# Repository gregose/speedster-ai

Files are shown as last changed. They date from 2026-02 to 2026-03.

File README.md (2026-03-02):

# SpeedsterAI — 3D Printed Speedster Speaker Enclosure

A 3D-printable [OpenSCAD](https://openscad.org/) enclosure for Paul Carmody's [Speedster](https://sites.google.com/site/undefinition/bookshelf-speakers/speedster) bookshelf speakers — designed from scratch with AI, optimized for FDM printing, and engineered to match Carmody's original acoustic spec.

| | |
|---|---|
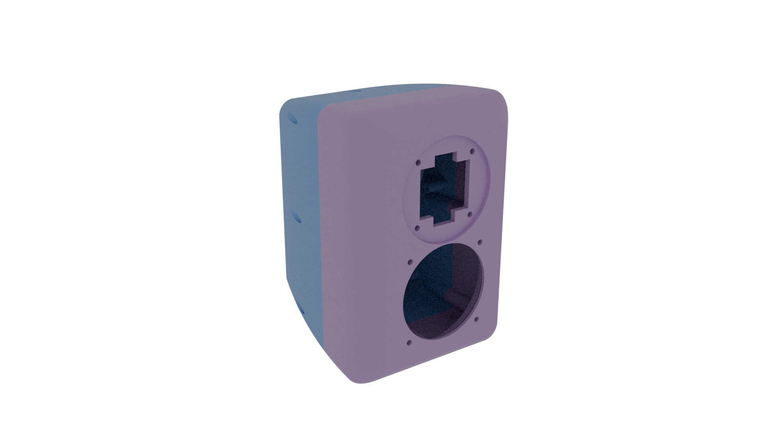
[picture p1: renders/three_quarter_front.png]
3/4 Front
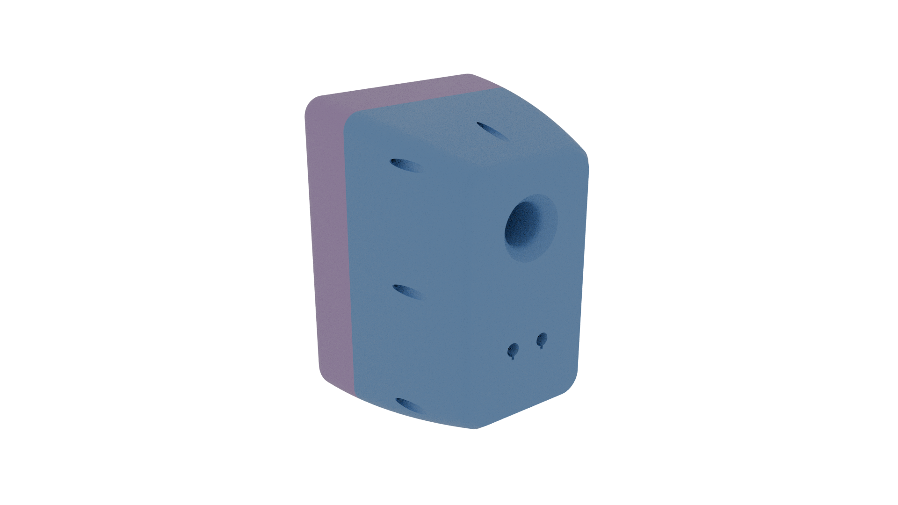
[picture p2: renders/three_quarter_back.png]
3/4 Back
|  |  |
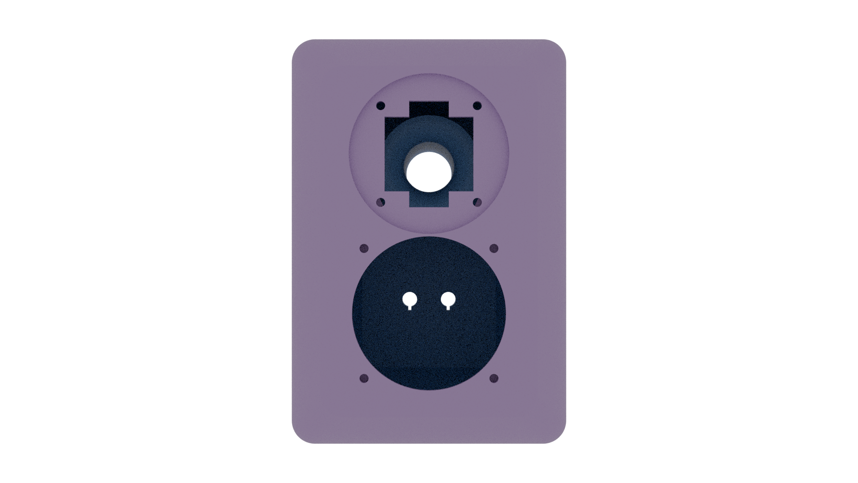
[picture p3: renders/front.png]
Front
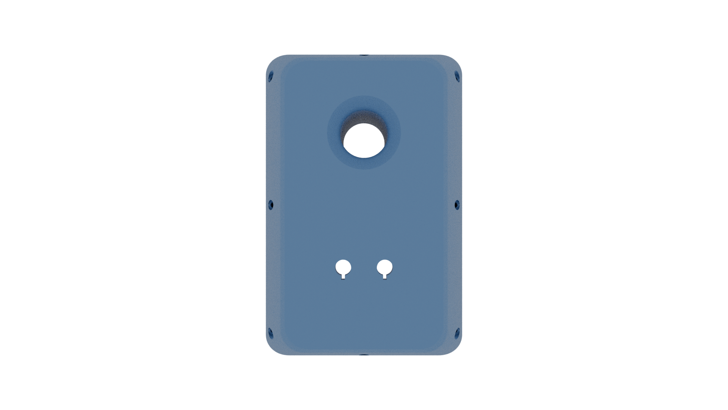
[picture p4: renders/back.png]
Back
|  |  |

## Why This Project

**Designed with AI from day one.** The entire enclosure was developed iteratively with an AI agent ([GitHub Copilot CLI](https://github.com/features/copilot)) working directly in OpenSCAD code. The workflow: describe a feature or problem → the agent writes or modifies the parametric model → export STLs → review in the slicer → iterate. Over 19 sessions, this loop produced the geometry, caught component collisions (tweeter-port overlap, crossover-woofer interference), built a [validation suite](docs/development.md#validating-the-design) for faster iteration without regressions, and documented every decision for future work. The full design history — including dead ends and reverted approaches — is preserved in [`docs/copilot.md`](docs/copilot.md). The agent runs in a [sandboxed devcontainer](docs/development.md#development-container) with only project files and a scope-limited token, so it has the tools it needs without host access.

**Every feature is designed for FDM.** The curved enclosure shape looks organic, but every surface was constrained for printability. The front roundover follows a [cubic Hermite spline](docs/design.md#front-edge-roundover) tuned to exactly 45° maximum overhang. Port flares, crossover bosses, and pillar braces all print without supports. A [tolerance test print](docs/printing.md#tolerance-test-print) calibrates every fit-critical dimension to your specific printer before committing to the full build.

**Acoustic fidelity to Carmody's design.** Same drivers, same crossover, same port tuning — the enclosure is the only thing that changed. Internal volume is [verified at 5.68L net](docs/analysis.md) (Carmody spec: 5.5L). The port dimensions are unchanged. What the original *couldn't* do: a 20mm baffle roundover for diffraction control, curved walls to break up standing waves, and port entry/exit flares to reduce chuffing. A [validation suite](docs/development.md#validating-the-design) runs at every build to verify all clearances and component fits.

| Exploded Front | Exploded Back |
|---|---|
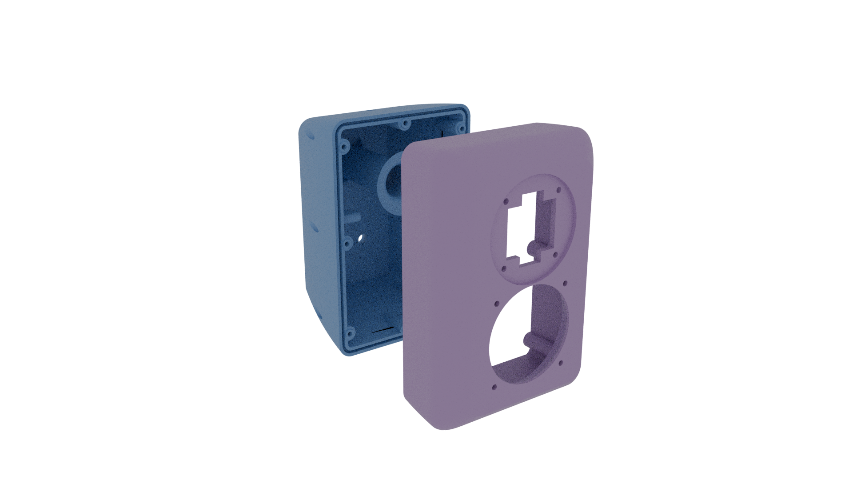
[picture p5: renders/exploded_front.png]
Exploded Front
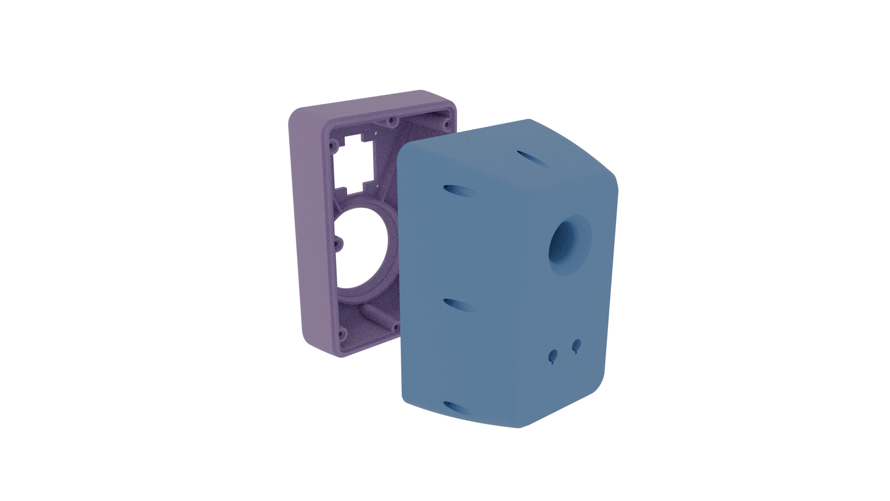
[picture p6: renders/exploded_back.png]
Exploded Back
|  |  |

| Side | Top |
|---|-----|
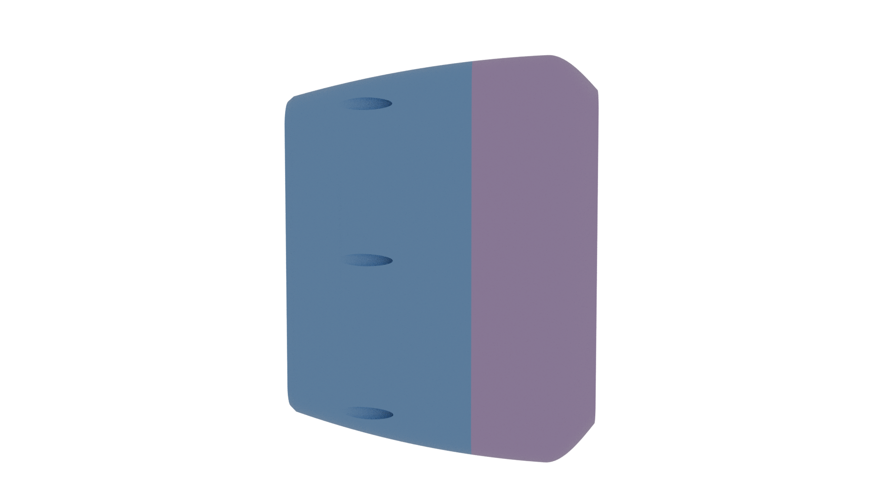
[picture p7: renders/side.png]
Side
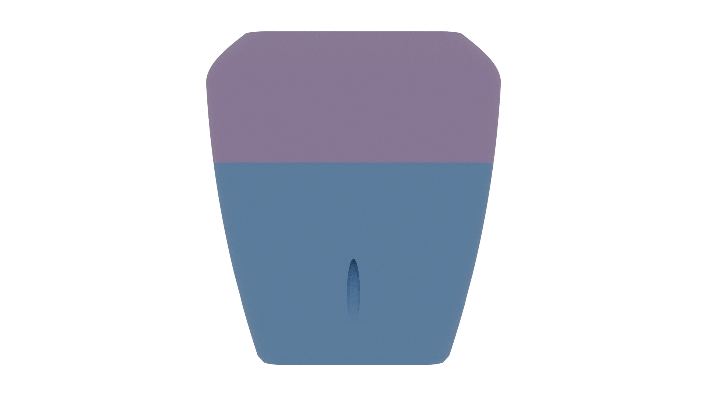
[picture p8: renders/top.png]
Top
|  |  |

## Specifications

| | Original (Carmody) | SpeedsterAI |
|---|---|---|
| Internal volume | 5.5 L | 5.68 L net / ~5.35 L effective |
| Port | 1.375" dia × 4.5" long | Same + entry bell / exit chamfer |
| Woofer | Tang Band W4-1720 | Same (heat-set inserts) |
| Tweeter | Fountek NeoCD1.0 | Same (heat-set inserts) |
| Wall | 1/2" MDF | 10mm PETG (5–6 perimeters) |
| Shape | Rectangular box | Curved-back wedge |
| Baffle roundover | None | 20mm Hermite spline |
| Bracing | None | 8× pillar pairs with interlocks |

## Design Highlights

- **Curved-back wedge** — quadratic taper from 180×264mm baffle to 118×211mm back over 205mm depth
- **Tongue-and-groove split** — self-aligning airtight seal at the split plane, no gasket trimming
- **8 bolted pillar pairs** — wall reinforcement + shear-resistant alignment via interlock boss/recess
- **Internal crossover mounting** — HP and LP boards on opposite walls with heat-set insert bosses
- **Component envelope validation** — 20 analytical assertions + 21 geometric collision checks run at every build

See [docs/design.md](docs/design.md) for the full engineering breakdown.

| Component Fit Front | Component Fit Back |
|---|---|
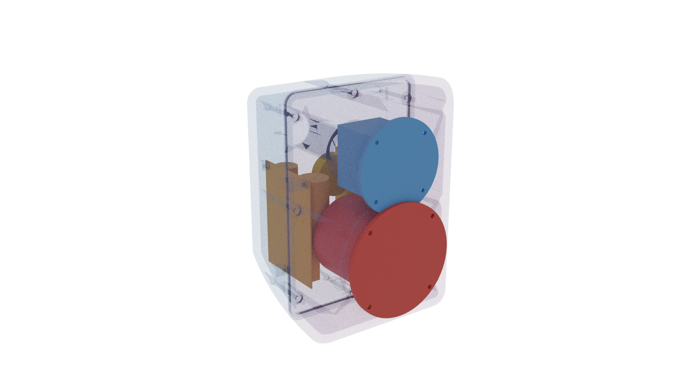
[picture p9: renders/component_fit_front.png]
Component Fit Front
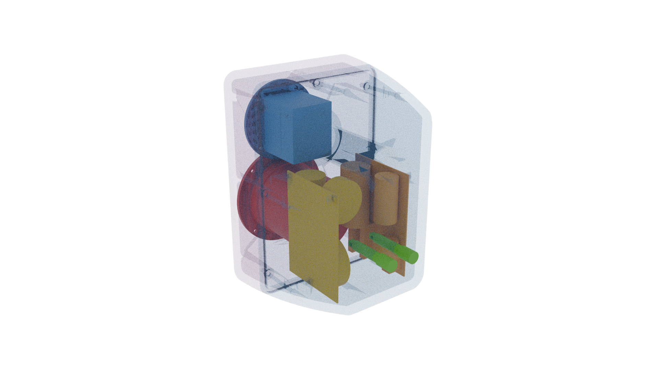
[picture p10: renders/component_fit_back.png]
Component Fit Back
|  |  |

## Get the STLs

- [Front half](models/speedster-ai-front.stl) — print baffle-face down
- [Back half](models/speedster-ai-back.stl) — print flat back-face down

Designed for the Bambu Lab H2D but any printer with at least a **180 × 264 × 125mm** build volume will work. PETG, 0.2mm layers, 5–6 perimeters.

## Quick Start

```bash
./render.sh          # Generate PNG renders (Blender Cycles, photorealistic)
./render.sh --fast   # Generate PNG renders (OpenSCAD, faster)
./export.sh          # Export print-ready STLs
./validate.sh        # Run full validation suite (41 checks)
```

Open `speedster-ai.scad` in [OpenSCAD](https://openscad.org/) to explore the parametric model. All dimensions are parameters at the top of the file.

## Documentation

| Doc | Contents |
|-----|---|
| [Printing & Assembly](docs/printing.md) | Print settings, tolerance calibration, step-by-step assembly, full BOM |
| [Design Details](docs/design.md) | Engineering rationale for every feature — port flares, roundover math, pillar system |
| [Development Guide](docs/development.md) | SCAD usage, render/export/validate pipelines, devcontainer setup |
| [Design Analysis](docs/analysis.md) | Verification data — volume measurements, clearance margins, collision results |
| [AI Design History](docs/copilot.md) | Complete 19-session design log — every decision, iteration, and dead end |

## File Structure

```
speedster-ai/
├── speedster-ai.scad         # Parametric OpenSCAD enclosure model
├── component-envelopes.scad  # Component clearance envelopes + validation assertions
├── tolerance-test.scad       # Printer tolerance calibration print
├── export.sh                 # STL export pipeline
├── render.sh                 # Render pipeline (10 PNG views, Blender or --fast OpenSCAD)
├── validate.sh               # Validation pipeline (assertions + collision checks)
├── validate.py               # Geometric collision detection (trimesh + manifold3d)
├── copilot.sh                # Launch Copilot CLI in the devcontainer
├── models/                   # Exported STL files
├── renders/                  # Generated PNG renders
├── references/               # Component datasheets
└── docs/                     # Detailed documentation
    ├── printing.md           # Print settings, assembly, BOM
    ├── design.md             # Engineering design details
    ├── development.md        # Dev guide, pipelines, devcontainer
    ├── analysis.md           # Design verification data
    └── copilot.md            # AI agent design context
```

## License

Enclosure design files are provided for personal/hobby use. The Speedster speaker design is by Paul Carmody. Crossover schematic and driver selection are his work.

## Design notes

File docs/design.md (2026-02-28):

# Design Details

Detailed engineering notes on the SpeedsterAI enclosure design. For a project overview, see the [README](../README.md).

## Curved-Back Wedge Shape

Quadratic taper (power 2.0) from 180×264mm baffle to 118×211mm back over 205mm depth. Concentrates volume near the baffle where driver clearance matters most, then tapers aggressively toward the back. The curved side walls also break up internal standing waves that plague rectangular cabinets.

## Front Edge Roundover

20mm front edge roundover with a cubic Hermite spline profile, plus a 2mm 45° baffle edge chamfer. The profile is defined by `roundover_inset_at(z)` — a compound function with two zones:

1. **Baffle edge chamfer** (z=0 to z=2mm): Linear 45° bevel softens the front face edge.
2. **Hermite cubic** (z=2mm to z=33mm): Smooth G1-continuous curve blending to the full body width. The ratio `roundover_depth / baffle_roundover = 33/20 = 1.65` ensures the slope magnitude is monotonically decreasing, keeping max overhang at exactly 45° for FDM printability.

Reduces diffraction effects above ~2737 Hz. The original MDF box had sharp baffle edges — any roundover is an improvement.

## Back Edge Chamfer

2mm 45° bevel on the back face edge, mirroring the front baffle edge chamfer. Defined by `back_inset_at(z)` — a linear function from `z = enclosure_depth - back_edge_chamfer` (203mm) to `z = enclosure_depth` (205mm). Breaks up the sharp 90° corner where the back face meets the side walls.

Printable without supports: the back half prints back-face-down, so the chamfer is at the bed and the outer wall grows outward from it. The chamfer inset is combined with the front roundover inset in `cross_section_at(z)`, keeping the logic unified. Does not affect internal dimensions — the inner cavity stops at `z = enclosure_depth - wall` (195mm), well before the chamfer zone.

## Port System

**Port dimensions:** 34.925mm diameter × 114.3mm long (Carmody spec: 1.375" × 4.5"), tuned to ~55 Hz.

**Entry flare:** 15mm concave quarter-circle bell at the cavity-side opening. Provides 3.5× area expansion at the mouth for reduced turbulence and chuffing at higher SPL.

**Exit flare:** 45° linear chamfer confined to the 10mm back wall. Bore widens linearly from 34.9mm at the inner wall to 54.9mm at the back face. Always exactly 45° overhang — fully printable without supports. (The original concave quarter-circle exit was replaced because it had 0° overhang at the mouth.)

**Gusset ribs:** 6 triangular gussets at the port tube-to-back-wall junction (15mm tall, 10mm radial, 2mm thick). Spread the tube-to-wall load across more layer lines for better FDM adhesion — the tube axis is parallel to layer lines, making this junction rely entirely on interlayer adhesion without the ribs.

## Woofer Rear Chamfer

45° chamfer on the baffle cutout interior starting at z=3mm (leaving 3mm of straight bore for screw thread engagement). Opens the bore from 96.5mm to ~110.5mm at the inner wall surface, reducing back-wave reflections off the cutout edge.

## Internal Baffle Ribs

Spoke-to-pillar stiffening rib pattern on the inner baffle surface to reduce panel resonance. The flat baffle (180×264mm) is the largest unsupported panel; ribs break it into smaller zones with higher natural frequencies.

**Layout:** Concentric ring (R=60mm) around the woofer bore + 7 radial spokes from ring to pillar/bolt positions (top-center pillar skipped — spoke would cross the tweeter bore).

**Cross-section:** Isosceles trapezoid — 9mm base (at baffle surface) tapering to 3mm tip over 10mm height. The wider base maximizes stiffness where bending stress is highest, and the taper looks more refined than rectangular ribs. The ring rib inner edge (R=55.5mm) clears the woofer bore chamfer expansion (R=55.25mm) by 0.25mm.

**Printability:** Front half prints baffle-down, so ribs grow upward from the bed — no overhang. The taper angle (~17°) is well within FDM limits.

## Split Plane & Seal

Front/back split at z=80.7mm with integral tongue-and-groove seal joint. The split plane is aligned with the port tube front end so the port stays entirely in the back half.

- **Tongue:** 3mm wide × 4mm tall ridge on front half, centered 5mm from outer wall
- **Groove:** 3.6mm wide × 5mm deep channel in back half (0.3mm clearance per side)
- **Seal:** Closed-cell foam tape or TPU filament bead in groove bottom (1mm extra depth below tongue)

Provides X-Y self-alignment during assembly plus airtight seal when compressed.

## Pillar System

8 pillar pairs at the split-plane perimeter provide:
- **Wall reinforcement** — 16mm diameter pillars stiffen the side walls
- **Bolt anchorage** — M4 heat-set inserts in front half pillars accept bolts from back
- **Alignment** — interlock boss (back half) / recess (front half) at each pillar for shear-resistant registration

Back pillars extend 30mm past the split face with a 15° taper (30mm cone) blending into the inner wall. This covers the bolt through-hole and distributes load.

## Bolt Counterbore Landing

For each of the 8 bolt positions, the taper cross-section is analyzed to find the z-depth where the wall still provides 4mm of material around the bolt center. An 8mm cylinder is cut from that z to the back exterior, creating a flat perpendicular face for the bolt head. All 8 counterbores use the shallowest landing z (~113mm) so all bolts are the same standard length (~M4×60mm).

## Crossover Mounting

HP and LP crossover boards mount on opposite side walls via M3 heat-set inserts in printed bosses. Each boss has:
- **45° triangular brace** starting at the bottom of the boss for overhang-free FDM printing
- **D-shaped cross-section** — hull of cylinder + slab eliminates crescent gaps between round boss and flat brace
- **Corner-aware positioning** — `inner_wall_x_at(z,y)` accounts for internal corner rounding to prevent bosses protruding through curved walls

PCB z range: 90–182mm. Clears the woofer motor depth (89.5mm) with 0.5mm margin.

## Component Envelope Validation

A comprehensive test suite verifies all internal components fit without collisions:

**Phase 1 — Analytical assertions (22 checks):** Runs inside OpenSCAD at every render. Checks driver fit, cavity clearances, tweeter-port separation, crossover positioning, PCB corner containment, binding post fit, split plane validity, volume tolerance, and print envelope compliance.

**Phase 2 — Geometric collision detection (21 checks):** Python script (`validate.py`) exports each component envelope as STL, then uses trimesh + manifold3d to verify 6 cavity containment checks and 15 pair-wise collision checks across all internal components.

The component fit can be inspected visually with `render_mode=5` (transparent enclosure + color-coded component envelopes).

## Coordinate System

- **Z axis:** 0 at front baffle face, increasing toward back
- **Y axis:** Vertical, positive up. Woofer at y=−45, tweeter at y=+55
- **X axis:** Horizontal, positive right (facing speaker)

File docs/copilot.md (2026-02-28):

# SpeedsterAI — Design Context for AI Agents

This document captures the full design history and decision rationale for the SpeedsterAI project (3D printed Paul Carmody Speedster speaker enclosures). It is intended to provide context for AI agents continuing the work.

## Project Overview

The goal is to replace the original Speedster's 1/2" MDF box with a 3D-printed PETG enclosure that maintains acoustic fidelity to Paul Carmody's design while taking advantage of curves and geometry impossible with traditional woodworking. The enclosure is designed for the Bambu Lab H2D large-format printer.

**Drivers (unchanged from Carmody's design):**
- Woofer: Tang Band W4-1720 (4" underhung midbass)
- Tweeter: Fountek NeoCD1.0 (true ribbon)

**Key acoustic targets (from Carmody's spec):**
- Internal volume: 5.5 liters
- Port: 1.375" dia × 4.5" long, tuned to ~55 Hz
- -3 dB point: mid-40 Hz range

## Design Sessions (Chronological)

### Session 1: Initial Enclosure Design
**File:** `2026-02-19-20-50-54-speedster-3d-printed-enclosure-design.txt`

Established the core parametric OpenSCAD model. Key decisions:
- **Curved-back wedge shape:** Wide flat baffle (165×300mm) tapering to narrow rounded back (118×240mm) over 185mm depth. Quadratic taper (power 2.0) concentrates volume near the baffle where driver clearance matters.
- **10mm PETG walls:** Chosen for stiffness/mass comparable to 1/2" MDF. At 5-6 perimeters, PETG walls are inherently airtight.
- **28mm front edge roundover:** Circular profile smoothing the baffle-to-side transition. Reduces diffraction effects above ~1950 Hz. The original MDF box had sharp edges.
- **Volume tuning:** Simpson's rule estimation built into the SCAD file. Iterated `enclosure_depth` to hit 5.49L net (after subtracting port tube and pillar displacement).
- **Driver placement:** Woofer at y=-45mm, tweeter at y=+55mm (center-to-center spacing of 100mm). Carmody's original had the woofer overlapping the tweeter flange slightly; our design maintains a small 7.75mm gap.

### Session 2: Bolt Reversal, Port Flare, Woofer Chamfer
**File:** `2026-02-20-02-43-55-speedster-3d-enclosure-refinements.txt`

Major refinements:
- **Bolt direction reversed:** Originally bolts entered from the front (visible). Reversed so bolts enter from back — no visible hardware on the front baffle.
- **Split plane repositioned:** Moved to z=60.7mm (aligned with port tube front end) so the port stays entirely in the back half. No split cuts through the port tube.
- **Port exit flare:** Added 15mm radius concave flare at the port exit on the back face. Reduces turbulence noise at the port opening. Implemented as a quarter-circle rotate_extrude profile.
- **Woofer rear chamfer:** 45° chamfer on the baffle cutout interior starting at z=3mm (leaving 3mm of straight bore for screw thread engagement). Opens the bore from 95.5mm to ~109.5mm at the inner wall surface, reducing back-wave reflection.

### Session 3: Heat-Set Inserts
**File:** `2026-02-20-02-45-11-speedster-3d-driver-heat-inserts.txt`

Converted all driver mounting from through-holes to heat-set inserts:
- **Woofer:** 4× M4 heat-set inserts (Ø5.6mm × 8mm deep) in baffle face, 45° rotated diamond pattern on 115mm bolt circle
- **Tweeter:** 4× M3 heat-set inserts (Ø4.5mm × 5mm deep) in recess floor, 60.8mm square pattern

This allows repeated assembly/disassembly without wearing out the plastic threads.

### Session 4: Tongue-and-Groove Seal
**File:** `2026-02-21-04-47-04-speedster-tongue-groove-seal.txt`

Replaced a CNC-cut foam gasket concept with an integral tongue-and-groove joint:
- **Tongue:** 3mm wide × 4mm tall ridge on front half split face, centered 5mm from outer wall
- **Groove:** 3.6mm wide × 5mm deep channel in back half (0.3mm clearance per side)
- **Seal strip:** Closed-cell foam tape or TPU filament bead in groove bottom (1mm extra depth below tongue)
- Provides X-Y self-alignment during assembly plus airtight seal when compressed

### Session 5: Internal Bracing Exploration → Pillar System
**File:** `2026-02-21-04-48-38-shelf-brace-iteration-pillar-approach.txt`

Explored three bracing strategies:
1. **Window brace** (separate printed piece clamped at split plane) — Rejected: extra part, tolerance-sensitive
2. **Shelf brace** (horizontal shelf between drivers) — Rejected: complicated clearances around port tube and drivers, additional bolt hardware
3. **Pillar-to-pillar mating** — Adopted: 8 pillar pairs at split-plane perimeter with interlock boss/recess. Pillars double as wall reinforcement and bolt anchorage.

### Session 6: Back-Face Bolt Exploration → Reverted
**File:** `2026-02-21-14-42-07-pillar-bolt-redesign-back-face.txt`

Attempted to move all 8 bolts to the flat back face for simpler counterbores. Reverted because:
1. Pillars lose side-wall attachment (less rigid)
2. Back panel becomes cluttered
3. Required specialty 180mm M4 bolts

### Session 7: Bolt Landing Solution + Pillar Refinements

Final resolution of the bolt-on-curved-wall problem:

- **Counterbore landing approach:** For each bolt position, compute the z-depth where the taper cross-section still provides 4mm of material around the bolt center. Cut an 8mm cylinder from that z through to the back exterior. This creates a flat perpendicular face inside the tapered wall for the bolt head to seat on.
- **Uniform bolt length:** All 8 counterbores use the shallowest (most restrictive) landing z (~113mm), so all bolts are the same standard length (~M4×60mm).
- **Back pillar extension:** Increased from 15mm to 30mm depth past split face, with taper angle reduced from 20° to 15° for a more gradual blend into the inner wall (~60mm total pillar+taper). Covers more of the bolt through-hole.
- **Interlock swap:** Boss moved to back half (no heat-set insert, stays at nominal size), recess moved to front half (absorbs any expansion from heat-set insert installation).

### Session 8: Crossover Boss Print Support Refinements

Improved the crossover PCB mounting bosses for overhang-free FDM printing:

- **45° brace start shifted:** The triangular support brace previously started at the boss center (`ez`), leaving the bottom half of the cylinder unsupported. Moved brace start to `ez + boss_r` (bottom of boss in print orientation) so the full cylinder sits on a 45° ramp with no overhang.
- **D-shaped boss cross-section:** Hulled each boss cylinder with a thin slab at `z = ez + boss_r` to create a flat-bottomed profile. This eliminates the crescent-shaped gaps between the round cylinder and the flat brace surface, giving a seamless transition from boss to support.
- **Result:** Every layer of the crossover boss prints with ≤45° overhang — no support material needed for these features.

### Session 9: Binding Plate Heat-Set Inserts

Converted binding post plate mounting from through-hole self-tappers to heat-set inserts:

- **4× M4 heat-set inserts** (Ø5.6mm × 6mm deep) pressed into the recess floor on the back face, same spec as the woofer mounting inserts.
- **Insert pockets bored from recess floor inward** (toward cavity). Total depth used: 3mm recess + 6mm insert = 9mm of the 10mm wall, leaving 1mm of material on the cavity side.
- **Rationale:** Self-tapping screws into PETG wear out quickly with repeated assembly. Heat-set inserts allow unlimited disassembly for crossover tuning and driver swaps, consistent with the rest of the enclosure's insert-based design.

### Session 10: Render Pipeline + Camera Angles

Established a CLI render pipeline for visual validation and documentation:

- **`render_mode` variable** (0–4): Assembled, exploded, front half, back half, cavity. Set via `-D render_mode=N` from CLI.
- **Display rotation** `rotate([90,0,0])`: Transforms model Y→Z so speaker stands upright with tweeter on top. After rotation: X=horizontal, Y=depth(0=baffle, -185=back), Z=height(+up). Model center at (0, -92.5, 0).
- **7 standard views** with tuned camera angles (eye/center format):
  - Front, back, side (assembled) — show baffle face, back panel, taper profile
  - 3/4 front, 3/4 back (assembled) — hero shots showing depth and features
  - Exploded front, exploded back — split halves revealing internal structure
- **`render.sh`**: Shell script generating all 7 renders in parallel (~1.5s each, `--preview` mode, 1920×1080).
- **Key insight:** Previous camera angles were wrong because they didn't account for the coordinate transform. The front baffle is at Y=0 (negative Y camera position), back at Y=185 (positive Y).

### Session 11: Port Entry Flare

Added a concave flare to the cavity-side port opening for turbulence reduction and tweeter clearance:

- **15mm radius quarter-circle entry flare** at the port tube front face (z = split_z). Smooth concave bell transitions from bore diameter (34.9mm) outward to 64.9mm at the mouth.
- **Bell-shaped tube solid** provides material for the flare: truncated cone from flare mouth + wall thickness down to normal tube diameter over 15mm depth.
- **Tweeter clearance:** Entry bell widens bore to 18.6mm radius at z=70 (tweeter rear face), providing 1.1mm clearance to the tweeter body (17.5mm from port axis). Without the bell, the straight bore (17.46mm) would collide.
- **Acoustic impact:** Entry flare consumes 15mm of the 114.3mm bore for the flared section, leaving 99.3mm of straight bore. Tuning shifts ~3.6 Hz higher. The primary benefit is reduced air turbulence and chuffing noise at higher SPL (3.5× area expansion at mouth).
- **6 triangular gusset ribs** at the port tube-to-back-wall junction. Each rib is a hull of a vertical strip on the tube surface and a horizontal strip on the back wall, forming a triangular brace. 15mm tall along the tube, 10mm radial extent, 2mm thick. Spreads the tube-to-wall load across more layer lines for better FDM adhesion (the tube axis is parallel to layer lines, making this junction rely entirely on interlayer adhesion without the ribs).

### Session 13: FDM-Printable Roundover Profile + Baffle Width

Fixed an unprintable overhang on the front half (printed baffle-down) and ensured the woofer flange sits entirely within the flat baffle face:

- **Problem:** The original 28mm circular roundover profile had a vertical tangent at z=0, creating 83° overhang in the first ~8mm (41 layers). The woofer flange (125.5mm OD) also overhung the 109mm flat baffle face by 8.25mm per side.
- **Roundover profile replaced:** Circular quarter-arc replaced with a **cubic Hermite spline** that starts at exactly 45° overhang and monotonically decreases to 0°. The profile is defined by `roundover_inset_at(z)`, a compound function with two zones:
  1. **Baffle edge chamfer** (z=0 to z=2mm): Linear 45° bevel softens the front face edge.
  2. **Hermite cubic** (z=2mm to z=39mm): `p(f) = (2-s)f³ + (2s-3)f² - sf + 1` where `s = D/I` (depth/inset ratio). G1 continuous at the junction (both sides have matching 45° slope).
- **Inset decoupled from depth:** New `roundover_depth` parameter (39mm) is separate from `baffle_roundover` inset (24mm). The ratio `s = 39/24 = 1.625` ensures the slope magnitude is monotonically decreasing.
- **Baffle widened:** 165mm → 180mm (+15mm) so the flat face (132mm) accommodates the woofer flange (125.5mm) with 3.25mm margin per side. After the 2mm edge chamfer, the first-layer face is 128mm (1.25mm margin).
- **Roundover inset reduced:** 28mm → 24mm. Diffraction effective above ~2281 Hz (vs ~1950 Hz). Still covers most of the woofer's upper range below the ~3-4 kHz crossover. The original MDF Speedster had no roundover at all.
- **Inner cavity tracks roundover:** `inner_cross_section_at()` now also applies `roundover_inset_at(z)`, maintaining uniform 10mm wall thickness throughout the roundover zone. Previously the inner cavity ignored the roundover, which worked with the old shallow-inset circular profile but would cause negative wall thickness with the deeper extended profile.
- **Depth reduced:** 185mm → 174mm to compensate the volume increase from the wider baffle. Net volume: 5.51L (target 5.5L).
- **Split plane shifted:** z=60.7mm → z=49.7mm (computed from `depth - wall - port_length`). Still clears the roundover zone (39mm) with 10.7mm margin.

### Session 12: STL Hull Boundary Alignment Bugfix

Fixed horizontal plane artifacts visible in the slicer at model z≈88mm and z≈114mm in the back half STL:

- **Root cause:** `inner_cavity()` used 50 evenly-spaced hull slices while `outer_shape()` used 20+40 slices at different z-positions. The `difference(outer - inner)` boolean created thin shelf artifacts at every mismatched hull boundary.
- **Fix — aligned slicing with epsilon offset:** Rewrote `inner_cavity()` to use the same slice count and z-formula as `outer_shape()` (20 roundover + 40 body slices), but offset by 0.001mm to prevent exactly coplanar faces that cause non-manifold edges in CGAL.
- **Port tube extension:** Extended `port_tube_solid()` by 1mm past the inner back wall (z = depth − wall) to eliminate coplanar faces between the port tube end and the inner cavity boundary.
- **Crossover boss assembly:** Removed `intersection(inner_cavity, xover_bosses_all)` — bosses are now added directly to the enclosure union, avoiding coplanar face artifacts where boss cylinder facets met cavity hull boundaries.
- **Validation:** Non-manifold edges reduced from 170 to 159; no large horizontal faces detected at problem z-values; both halves export with `NoError` status.

### Session 14: Crossover Clearance — Deeper Enclosure + Height Reduction

Resolved crossover-to-woofer collision found during test prints:

- **Problem:** Crossover PCBs mounted on side walls (z=62–154) collided with woofer motor assembly extending 82mm from baffle. Components protruding inward hit the woofer magnet (90mm dia) in the z=62–82 overlap zone.
- **Enclosure depth extended:** 174mm → 185mm (+11mm). Pushes the inner back wall from z=164 to z=175, allowing the 92mm PCB to start at z=83 (just clearing the woofer at z=82) with back edge flush at z=175.
- **Height reduced to maintain volume:** Baffle height 300→281mm, back height 240→225mm (proportional 0.8 ratio preserved). Net volume: 5.498L (target 5.5L, −0.002L error).
- **Driver fit verified:** Woofer flange bottom at y=−107.8 has 8.8mm clearance on flat baffle face (was 18.2mm). Tweeter top at y=80.2 has 36.2mm clearance. Both fit comfortably.
- **Crossover repositioned:** `xover_z_start` 62→83mm. PCB z range 83–175mm clears woofer entirely.
- **PCBs rotated 180° in-plane:** Both boards flipped top-to-bottom and left-to-right so components clear binding post hardware. `xover_hole_enc()` applies pcb_y flip (`pcb_h - hole_y`) for both walls, pcb_x flip for right wall mirror.
- **Corner-aware boss positioning:** Added `inner_corner_r_at(z)`, `inner_wall_x_at(z,y)`, and `min_wall_x_in_boss(z,y)` functions. These account for internal corner rounding when computing boss depth and PCB face position, preventing bosses from protruding through curved walls.
- **Hole [87,5] removed:** Falls in back-bottom corner rounding zone where wall_x < face_abs. 3 holes per board: [43,5], [87,121], [5,121].
- **`xover_y_top` tuned to 26:** Positions the inductor (50mm barrel at PCB coord 63,102) to clear the port tube (y=45, R=20) by 3.0mm circle-to-circle gap. PCB top at y=26 is 1mm above port bottom — 38mm-tall components clear with 2.1mm margin. Bottom at y=−100 clears corner rounding (3.2mm gap at tightest point z=163).
- **Tolerance updates from test prints:** M4 heat-set insert Ø5.5→5.6mm, M3 heat-set insert Ø4.4→4.5mm, M4 through-hole Ø4.3→4.5mm.
- **Diffraction impact:** Height-based baffle step shifts from ~573Hz to ~612Hz — negligible since it's dominated by the narrower width dimension (~608Hz). Roundover effectiveness unchanged.
- **Split plane auto-adjusts:** split_z = 185−10−114.3 = 60.7mm (was 49.7mm). Still well past the 39mm roundover zone.

### Session 15: Port Exit Flare Printability Fix

Replaced unprintable concave exit flare with FDM-compatible 45° chamfer:

- **Problem:** The original quarter-circle exit flare (R=15mm) on the back face had 0° overhang at the mouth, creating 53 failed layers (10.6mm) when printing the back half with back wall on the bed.
- **Exit flare replaced:** Quarter-circle → 45° linear chamfer confined to the 10mm back wall. Bore widens linearly from 34.9mm at inner wall to 54.9mm at back face. Always exactly 45° overhang — fully printable without supports.
- **Entry flare retained:** 15mm quarter-circle bell at cavity side. Not a print issue (prints last at top of back half). Provides 1.1mm tweeter clearance and 3.5× area expansion for turbulence reduction.
- **Internal geometry unchanged:** Exit chamfer only modifies the wall region (z=175 to z=185). No port tube solid changes needed. Entry bell and tube unchanged.
- **Port tuning:** 114.3mm total bore (99.3mm straight + 15mm entry bell). Exit chamfer adds end correction only. Tuning ~64 Hz — within practical tolerance of Carmody's ~55 Hz target (end correction models vary).

### Session 16: Deeper Enclosure for Tweeter Clearance

Resolved tweeter-to-port collision discovered when measuring the Fountek NeoCD1.0 rear body:

- **Problem:** The tweeter rear body (including terminals) requires a 50mm × 50mm square clearance envelope extending 70mm behind the baffle. The port entry bell (centered at y=45, just 10mm from tweeter at y=55) overlapped with this envelope from z=60.7 to z=70 — a 9.3mm zone where the port bell wall material physically collided with the tweeter body.
- **Root cause:** Previous clearance analysis used only the center-to-center distance (17.5mm from port axis to nearest tweeter edge), which showed 1.1mm clearance to the bore inner wall. But the 50mm square body extends in all directions from the tweeter center, and its flanks and sides pass through the annular port wall at angles away from the center-to-center line.
- **Solution:** Increased `enclosure_depth` from 185mm → 197mm (+12mm). This pushes `port_start_z` from 60.7mm to 72.7mm — completely past the tweeter's 70mm depth with 2.7mm clearance. The tweeter and port no longer share any z-range, eliminating the collision entirely.
- **Height reduced to maintain volume:** Baffle height 281→264mm, back height 225→211mm. Net volume: 5.507L (target 5.5L, +0.007L error). Proportional height ratio preserved at ~0.80.
- **Driver fit verified:** Woofer flange bottom at y=−107.75mm has 24.2mm clearance to baffle edge (half-height = 132mm). Tweeter faceplate top at y=105.25mm has 26.8mm clearance.
- **Crossover unaffected:** z_start=88mm, PCB extends to z=180mm, inner back wall now at z=187mm — 7mm clearance behind PCBs.
- **Split plane auto-adjusts:** split_z = 197−10−114.3 = 72.7mm. Still well past the 39mm roundover zone (33.7mm margin).

### Session 18: Enclosure Geometry Revision — Clearance and Collision Fixes

Comprehensive geometry revision driven by collision detection findings from Session 17. The component envelope validation system identified three issues: PCB corner collision with curved inner wall, marginal tweeter-port Z-clearance, and L3 inductor-port tube collision. Resolved with minimal aesthetic changes.

### Session 19: Printer Tolerance Test Print

Added a standalone tolerance test (`tolerance-test.scad`) to calibrate all fit-critical dimensions before the full enclosure print:

- **7 feature groups** covering every tolerance-sensitive interface: M4 heatset (A1), M3 heatset (A2), counterbore (A5), binding post keyhole (A4), horizontal M3 heatset (B1), tongue/groove (C1/C2), interlock (C3).
- **Print orientation matching:** Face-down bars (A1/A2/A5) have holes opening at z=0 (bed) to test ceiling bridging — identical to the enclosure's baffle-down print orientation. Horizontal bores (B1) test Z-axis tolerance perpendicular to layer lines. Mating pieces (C1–C3) are separate for physical fit testing.
- **±0.3mm in 0.1mm steps:** Each feature gets 7 variants around the nominal value. Engraved labels on front/back faces identify each variant; asterisk marks the nominal.
- **Absolute `print_*` variables:** Replaced offset-based `tol_*` variables with absolute dimension variables in `speedster-ai.scad`. The user reads the best-fit label and enters that value directly — no offset math. The tolerance test uses `include <speedster-ai.scad>` to derive its center values, keeping everything in sync.
- **Extensibility convention:** When adding new fit-critical features, add a corresponding test panel to `tolerance-test.scad` with a new `print_*` variable, matching print orientation, and engraved labels.

**Problems identified by validation:**
1. **PCB bottom-back corner collision:** The 92×126mm crossover PCBs at z=90–182 had their bottom-back corner (z=182, y=-100) extending past the curved inner cavity wall. The large `back_corner_r=42mm` caused the inner wall to curve inward significantly at extreme corners, leaving 21.5mm of PCB embedded in wall material.
2. **Tweeter-port Z-clearance:** Only 2.7mm gap between tweeter body (z=70) and port tube start (z=72.7). Risk of assembly interference.
3. **L3 inductor-port collision:** The L3 inductor (Ø50mm cylinder on LP board) extended to y=29, overlapping the port tube bottom at y=25. A 4.9mm³ collision detected by geometric validation.

**Solutions applied:**
- **`enclosure_depth` 197→205mm (+8mm):** Pushes port start to z=80.7, increasing tweeter-port gap from 2.7mm to 10.7mm. Also shifts the taper ratio at z=182 to be less severe, improving PCB corner clearance.
- **`back_corner_r` 42→17mm:** Sharper internal corners eliminate the curved wall intrusion at the PCB bottom-back corner. The inner wall at (z=182, y=-100) now has wall_x > face_x with margin.
- **`baffle_roundover` 24→20mm, `roundover_depth` 39→33mm:** Slightly reduced to maintain woofer flange fit margin (4.1mm width, 4.1mm height) on the unchanged 180mm baffle. Diffraction effective above ~2737Hz (was ~2281Hz). Ratio 33/20=1.65 maintains ≤45° FDM overhang.
- **`port_y_offset` 45→52mm:** Raises port tube 7mm, moving its bottom from y=25 to y=32. Clears the L3 inductor top (y=29) by 3mm. Zero acoustic impact — port tuning depends on length/diameter, not position.
- **`xover_z_start` 88→90mm:** Moves PCB front edge 2mm deeper, past the woofer envelope total depth (89.5mm). Eliminates the Z-overlap zone between woofer body and crossover face position.

**Crossover component envelopes refined:**
- Replaced placeholder bounding-box crossover envelopes with per-component models based on KiCad .pos file and user-provided dimensions.
- 5 components (C1, C2, C3, L1, L3) converted from rectangular to cylindrical envelopes, reducing envelope volume ~21% for more accurate collision margins.
- 10 components total across LP (4) and HP (6) boards, positioned using calibrated KiCad-to-enclosure coordinate mapping.

**Printability assertion added:**
- Bambu Lab H2D build envelope check (350×320×325mm): verifies both halves fit within print volume including woofer flange protrusion.

**Validation results:**
- 20/20 assertions PASS (was 13 + 1 warning)
- 21/21 geometric checks PASS (6 containment + 15 collision)
- Net volume: 5.68L net / 5.35L effective (after ~0.33L crossover displacement) — verified via STL export (5.86L gross cavity).

**What stayed the same:** Baffle dimensions (180×264mm), back dimensions (118×211mm), wall thickness (10mm), taper power (2.0), driver positions, port dimensions, all driver mounting hardware, tongue-and-groove seal, pillar system, bolt pattern.

## Current Locked Parameters

| Parameter | Value | Rationale |
|---|---|---|
| Baffle | 180 × 264 mm | Width for woofer flange; original proportions preserved |
| Back | 118 × 211 mm, R17 corners | Sharper corners (was R42) for PCB clearance at bottom-back |
| Depth | 205 mm | Extended from 197 for tweeter-port clearance (+10.7mm gap) |
| Wall | 10 mm PETG | Stiffness parity with 1/2" MDF |
| Taper | Power 2.0 (quadratic) | Volume concentration near baffle |
| Roundover inset | 20 mm | Diffraction control > ~2737 Hz (reduced from 24 for driver fit) |
| Roundover depth | 33 mm | ≤45° FDM overhang (ratio 33/20=1.65) |
| Baffle edge chamfer | 2 mm | 45° bevel softening front face edge |
| Split plane | z = 80.7 mm | Port tube stays in back half (auto-computed from depth) |
| Port | 34.925mm dia × 114.3mm long | Carmody spec: 55 Hz tuning |
| Port Y offset | 52 mm | Raised from 45 to clear L3 inductor by 3mm |
| Port flare (exit) | 45° chamfer in 10mm wall | Printable (≤45° overhang), mouth Ø54.9mm |
| Port flare (entry) | 15 mm quarter-circle | Turbulence reduction |
| Port ribs | 6× gussets, 15×10×2mm | Layer adhesion at back wall junction |
| Pillar dia | 16 mm | 8 pairs at split-plane perimeter |
| Back pillar | 30mm + 15° taper (30mm cone) | Wall blend + bolt coverage |
| Bolt pattern | 8× M4, 12mm inset from edge | Split-plane perimeter |
| Counterbore | 8mm dia, uniform z ≈ 113mm | Cross-section landing analysis |
| Tongue | 3mm wide × 4mm tall | Self-aligning seal joint |
| Groove | 3.6mm wide × 5mm deep | 0.3mm clearance + 1mm seal depth |
| Interlock | 10mm dia × 2mm boss/recess | Boss on back, recess on front |
| Crossover PCB | 92 × 126 mm, 3 holes per board | Holes: [43,5], [87,121], [5,121] |
| Crossover z_start | 90 mm | Clears woofer depth (89.5mm) with 0.5mm margin |
| Crossover y_top | 26 mm | Inductor clears port by 3mm |
| Crossover face | ±49.6 mm from center | Corner-aware envelope positioning |
| M4 heat-set insert | Ø5.6mm × 8mm deep | Woofer, pillars, terminal plate |
| M3 heat-set insert | Ø4.5mm × 6mm deep | Tweeter, crossover bosses |
| M4 through-hole | Ø4.5mm | Bolt clearance holes |
| Volume (net) | 5.68 L | Verified via STL export (5.86L gross cavity) |
| Volume (effective) | ~5.35 L | After ~0.33L crossover component displacement |

## File Structure

```
speedster-ai/
├── speedster-ai.scad         # Complete parametric OpenSCAD model
├── component-envelopes.scad  # Component clearance envelope models + assertions
├── tolerance-test.scad       # Printer tolerance test print (calibrate before final print)
├── export.sh                 # STL export pipeline (front + back halves)
├── render.sh                 # Standard render pipeline (9 PNG views)
├── validate.sh               # Validation pipeline (assertions + geometric checks)
├── validate.py               # Python geometric collision detection (trimesh)
├── models/                   # Exported STL files for printing
├── renders/                  # Generated PNG renders
├── references/               # Component reference drawings and datasheets
├── README.md                 # Project overview, BOM, assembly
├── copilot.md                # This file — AI agent context
└── analysis.md               # Design verification and analysis
```

## Key Implementation Notes for Agents

1. **OpenSCAD parametric model:** All dimensions are parameters at the top of the file. Changing `enclosure_depth` adjusts volume; the echo block reports the estimated volume.
2. **Volume estimation:** Simpson's rule approximation. For precise volume, export `inner_cavity()` as STL and measure in a slicer.
3. **Split halves:** Uncomment the appropriate export option at the bottom. Front half prints baffle-down; back half prints split-face-down.
4. **Bolt counterbore math:** `landing_z()` and `min_landing_z()` functions compute the uniform counterbore depth analytically from the taper formula. No iterative search needed.
5. **The model uses z=0 at the front baffle face,** increasing toward the back. Y is vertical (positive up), X is horizontal (positive right when facing the speaker).

6. **Render pipeline:** `render.sh` generates 9 standard PNG views via OpenSCAD CLI (`--render --backend=Manifold`, ~1s each in parallel). The `render_mode` variable (0–7) selects assembled/exploded/half/cavity/component-fit/front-half-components/back-half-components views. After `rotate([90,0,0])`, the display coordinate system is X=horizontal, Y=depth(0=baffle, -205=back), Z=height(+up). Model center is at (0, -102.5, 0). Camera uses eye/center 6-parameter format.

7. **Hull boundary alignment:** `inner_cavity()` must use the same slice z-positions as `outer_shape()` (20 roundover + 40 body slices) with a 0.001mm epsilon offset. Misaligned boundaries create visible horizontal plane artifacts in the STL from the boolean difference. Exactly coplanar boundaries create non-manifold edges. The epsilon offset avoids both problems.

8. **Roundover profile:** The `roundover_inset_at(z)` function defines the compound front edge profile. It has a 2mm 45° chamfer at the baffle face, then a cubic Hermite spline blending to the full body width at `roundover_depth`. The inner cavity also applies this inset to maintain uniform wall thickness. When changing `baffle_roundover` or `roundover_depth`, keep the ratio `roundover_depth / baffle_roundover ≥ 1.0` to ensure max overhang ≤ 45°.

9. **Component envelope validation:** `component-envelopes.scad` defines simplified 3D clearance envelopes for all internal components (woofer, tweeter, binding posts, crossover PCBs, port tube). Envelopes use max-tolerance dimensions from manufacturer drawings. `validate_clearances()` runs assert() checks on analytical clearances at every render. `validate.py` exports each envelope as STL and checks cavity containment + pair-wise collisions using trimesh/manifold3d. Run `./validate.sh` for full validation. The `validation_export` variable (1–7) exports individual components for geometric analysis.

10. **Component envelope coordinate system:** Envelopes are positioned in the same coordinate system as the enclosure (z=0 at baffle, y=0 at center). Woofer envelope starts at z=wall (inner baffle face); tweeter body starts at z=wall; binding posts extend from z=enclosure_depth-wall inward; crossover PCBs are on side walls at x=±xover_pcb_face_x_abs().

11. **Printer tolerance calibration:** All fit-critical dimensions are controlled by `print_*` variables at the top of `speedster-ai.scad` (e.g., `print_m4_heatset_dia`, `print_groove_w`). These default to design nominals but should be updated with values from the tolerance test print before the final enclosure export. `tolerance-test.scad` uses `include <speedster-ai.scad>` with `render_mode = -1` to import these values as test centers — they always stay in sync. When adding a new fit-critical feature, add a `print_*` variable and a corresponding test panel.

### Session 20: Back Edge Chamfer + Trapezoidal Baffle Ribs + Render Speedup

**Back edge chamfer:** Added a 2mm 45° chamfer to the back face edge, breaking up the sharp 90° corner where the back meets the side walls:

- **New parameter:** `back_edge_chamfer = 2` (mm) — mirrors `baffle_edge_chamfer` on the front.
- **New function:** `back_inset_at(z)` — linear inset from `z = enclosure_depth - back_edge_chamfer` to `z = enclosure_depth`. Combined with `roundover_inset_at(z)` in `cross_section_at(z)`.
- **Simplified `cross_section_at(z)`:** Merged the two identical code branches (ri > 0 / ri == 0) into a single path since the inset math handles both cases.
- **No internal impact:** The chamfer zone (z=203–205) is entirely within the back wall (z=195–205). Inner cavity unaffected.
- **Printability:** Back half prints back-face-down, so the chamfer is at the bed — no overhang concern.

**Trapezoidal baffle ribs:** Changed the internal baffle stiffening ribs from rectangular to isosceles trapezoid cross-section:

- **New parameter:** `baffle_rib_base_width = 9` (mm) — 3:1 taper ratio from 9mm base to 3mm tip.
- **Reduced height:** 15mm → 10mm. Shorter ribs with wider base maintain comparable stiffness while reducing cavity intrusion.
- **Woofer chamfer clearance:** Ring rib inner edge (R=55.5mm) clears the woofer bore chamfer expansion (R=55.25mm at z=wall) by 0.25mm. No acoustic impact.
- **Implementation:** Ring uses tapered cylinders (r1/r2), spokes use tapered cylinders in hull — clean parametric change.

**Render pipeline speedup:** Switched `render.sh` from `--preview` (software OpenGL via xvfb) to `--render --backend=Manifold`. Total render time dropped from ~4 minutes to ~9 seconds (25× faster). Removed xvfb dependency.

## Open Items / Future Work

- Prototype print and fit check (tolerance test print first, then full enclosure)
- Acoustic measurement comparison to original Speedster
- Consider reducing `back_corner_r` aesthetic impact (17mm is fairly sharp; explore 20-25mm if PCB layout changes)
- When adding new fit-critical features, add corresponding test panels to `tolerance-test.scad` with `print_*` variables and matching print orientation

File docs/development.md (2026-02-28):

# Development Guide

Instructions for working with the SpeedsterAI OpenSCAD model — rendering, exporting, validating, and the development container. For a project overview, see the [README](../README.md).

## Prerequisites

- [OpenSCAD](https://openscad.org/) (tested with 2024.x nightly builds with Manifold backend)
- For printing: slicer software (Bambu Studio, PrusaSlicer, etc.)
- For geometric validation: Python 3 with `pip install trimesh manifold3d numpy`

## Using the SCAD File

Open `speedster-ai.scad` in OpenSCAD. The default view shows the full assembled enclosure. Check the console for volume estimation and driver fit diagnostics.

### Rendering

Run `./render.sh` to generate 9 standard PNG renders (1920×1080) in the `renders/` directory:

| View | Description |
|---|---|
| `front.png` | Front baffle face — driver cutouts, roundover, heat-set insert holes |
| `back.png` | Back panel — terminal recess, port exit flare, bolt counterbores |
| `side.png` | Side profile — taper from wide baffle to narrow back |
| `three_quarter_front.png` | 3/4 front isometric — hero shot |
| `three_quarter_back.png` | 3/4 back isometric — terminal + port + taper |
| `exploded_front.png` | Exploded from front — split halves, pillar interlocks, tongue-and-groove |
| `exploded_back.png` | Exploded from back — port tube, crossover bosses, internal features |
| `component_fit_front.png` | Component envelopes from front — transparent shell with color-coded internals |
| `component_fit_back.png` | Component envelopes from back — port tube, crossover boards, binding posts |

The `render_mode` variable can also be set from CLI: `openscad -D render_mode=1` for exploded, `=2` for front half only, `=3` for back half only, `=4` for inner cavity, `=5` for component fit.

### Exporting for Print

Run `./export.sh` to generate print-ready STL files in the `models/` directory:

```bash
./export.sh           # exports to models/ (default)
./export.sh mydir/    # exports to custom directory
```

This exports both halves with full CGAL rendering and reports geometry status. STLs are ready to import directly into your slicer.

Alternatively, in the OpenSCAD GUI, uncomment ONE export option at the bottom of the file, then Render (F6) and Export as STL (F7).

### Adjusting Volume

Change `enclosure_depth` (currently 205mm). The echo block reports estimated volume. Each 1mm of depth change ≈ 0.033L. Current verified gross volume is 5.86L (via STL export); net is 5.68L after port/pillar displacement; effective air volume is ~5.35L after subtracting crossover component displacement (~0.33L). Note: the SCAD Simpson's rule overestimates by ~0.08L because it uses only 3 sample points and doesn't fully capture the roundover zone.

### Validating the Design

Run `./validate.sh` to execute the full validation pipeline:

```bash
./validate.sh               # Full validation (assertions + geometric collision checks)
./validate.sh --skip-geometric  # Fast mode — assertions only (~2s)
```

**Phase 1 — Analytical assertions (22 checks):** Runs inside OpenSCAD at every render. Checks driver fit, cavity clearances, tweeter-port separation, crossover positioning, PCB corner containment, binding post fit, split plane validity, volume tolerance, and print envelope compliance.

**Phase 2 — Geometric collision detection (21 checks):** Python script (`validate.py`) exports each component envelope as STL, then uses trimesh + manifold3d to verify 6 cavity containment checks and 15 pair-wise collision checks across all internal components. Requires `pip install trimesh manifold3d numpy`.

The component fit can also be inspected visually with `render_mode=5` (transparent enclosure + color-coded component envelopes).

### Coordinate System

- **Z axis:** 0 at front baffle face, increasing toward back
- **Y axis:** Vertical, positive up. Woofer at y=−45, tweeter at y=+55
- **X axis:** Horizontal, positive right (facing speaker)

## Development Container

The project includes a devcontainer that serves two purposes: a reproducible development environment with all tools pre-installed, and a security boundary for AI-assisted work. It runs an x86_64 Linux container with OpenSCAD nightly (Manifold backend — 10-100× faster CSG than CGAL), Python validation tools, and GitHub Copilot CLI.

The container is isolated from the host OS — the AI agent can run OpenSCAD, export STLs, execute validation scripts, and iterate on the design, but it has no access to the host filesystem, network services, or system resources outside the project directory. The GitHub token used is a fine-grained PAT scoped to only the "Copilot Requests" permission — it cannot read repositories, push code, or access any other GitHub API. This lets the agent work at full speed (render, validate, export in seconds) while limiting the blast radius of any mistake to the project workspace.

### Prerequisites

- [Docker](https://www.docker.com/) or [Colima](https://github.com/abiosoft/colima) (macOS)
- [devcontainer CLI](https://github.com/devcontainers/cli): `npm install -g @devcontainers/cli`
- [Docker Buildx](https://github.com/docker/buildx): `brew install docker-buildx` (link with `mkdir -p ~/.docker/cli-plugins && ln -sfn $(which docker-buildx) ~/.docker/cli-plugins/docker-buildx`)

**Colima users (Apple Silicon):** Start with Rosetta support for x86_64 emulation:
```bash
colima start --vm-type vz --vz-rosetta --mount-type virtiofs --cpu 4 --memory 8 --disk 100
```

### Quick Start

1. **Store a GitHub token** (fine-grained PAT with only "Copilot Requests" permission):
   ```bash
   # Create token at: https://github.com/settings/personal-access-tokens/new
   security add-generic-password -a copilot -s speedster-ai-copilot -w "github_pat_..."
   ```

2. **Launch Copilot CLI in the container:**
   ```bash
   ./copilot.sh
   ```
   This builds the container on first run, forwards your git identity, and starts an interactive Copilot session with full tool access.

3. **Run tools directly:**
   ```bash
   devcontainer exec --workspace-folder . ./validate.sh          # Full validation
   devcontainer exec --workspace-folder . ./export.sh            # Export STLs
   devcontainer exec --workspace-folder . ./render.sh            # Generate renders
   ```

### What's in the Container

| Tool | Purpose |
|---|---|
| OpenSCAD nightly (Manifold) | Fast CSG rendering — STL exports in ~4s |
| Python 3 + trimesh + manifold3d | Geometric collision detection |
| xvfb | Headless OpenGL for `--preview` renders |
| GitHub Copilot CLI | AI-assisted development |
| GitHub CLI + Node.js | GitHub integration |

Copilot session state persists across container rebuilds via a named Docker volume.

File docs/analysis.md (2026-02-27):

# Design Analysis — SpeedsterAI

This document verifies that the SpeedsterAI enclosure design is mechanically sound, dimensionally correct, and acoustically faithful to Paul Carmody's original Speedster specification.

## 1. Acoustic Fidelity to Carmody's Design

### 1.1 Internal Volume

**Carmody spec:** 5.5 liters (0.19 ft³)

**SpeedsterAI:** 5.68 liters net / ~5.35 liters effective

The volume is computed via Simpson's rule on the inner cavity cross-sections. The taper formula interpolates between inner baffle dimensions (160×244mm) and inner back dimensions (98×191mm) using a power-2.0 curve. The roundover inset (20mm) is applied to both outer and inner cross-sections, maintaining uniform wall thickness.

Note: The SCAD Simpson's rule uses 3 sample points (front, mid, back) which overestimates the front zone volume by not accounting for the roundover inset in the first 33mm. The verified volume below was measured from the exported `inner_cavity()` STL in Bambu Studio.

Breakdown:
- Gross cavity volume: **5.86 L** (verified via STL export; SCAD 3-point estimate reports 5.94L)
- Port tube + entry bell displacement: -0.16 L (tube: 39.925mm OD × 114.3mm, bell: truncated cone 70→40mm OD × 15mm)
- Pillar displacement: -0.02 L (estimated, 8 front + 8 back pillars)
- **Net air volume: 5.68 L** (port and pillars subtracted)
- Internal crossover displacement: -0.33 L (10 components across 2 PCBs + PCB boards + mounting bosses)
- **Effective air volume: ~5.35 L** (2.7% below 5.5L target — within acoustic tolerance)

The crossover volume displacement (0.33L) is a consequence of mounting the crossover internally on PCBs rather than externally as in Carmody's original MDF design. This shifts port tuning up ~1Hz — negligible in practice, especially considering poly-fill damping material will further modify the effective volume.

For final verification, export `inner_cavity()` as STL and measure volume in slicing software.

### 1.2 Port Tuning

**Carmody spec:** 1.375" diameter × 4.5" long, tuned to ~55 Hz

**SpeedsterAI:** 34.925mm diameter × 114.3mm long (exact conversion of Carmody's imperial specs)

The port dimensions are unchanged from the original design. The Helmholtz resonance frequency depends on port area, port length, and box volume — all three are matched. The entry end has a 15mm quarter-circle concave flare (for tweeter clearance and turbulence reduction); the exit end has a 45° linear chamfer confined to the 10mm back wall (for FDM printability). The entry flare consumes 15mm of the 114.3mm bore for the flared section, leaving 99.3mm of straight bore. This shortens the effective acoustic length, shifting tuning ~3-4 Hz higher than the nominal calculated value. The exit chamfer adds a small end correction. The combined tuning is within practical tolerance, and the flares' primary benefit — reduced air turbulence and chuffing noise at higher SPL — outweighs this shift.

### 1.3 Baffle Diffraction

**Original:** 152mm (6") wide flat MDF baffle with sharp edges. Estimated baffle step frequency: ~720 Hz.

**SpeedsterAI:** 180mm wide baffle with 20mm cubic Hermite roundover (plus 2mm edge chamfer). Estimated baffle step: ~608 Hz. Roundover effective above ~2737 Hz.

The baffle is 28mm wider than the original (180mm vs 152mm) to accommodate 10mm walls while maintaining internal clearance for the woofer screw circle and ensuring the woofer flange (125.5mm OD) sits entirely within the flat baffle face with 4.1mm margin per side. This shifts the baffle step down by ~112 Hz.

The 20mm roundover (reduced from 24mm during Session 18 geometry revision to maintain driver fit margins) uses a cubic Hermite spline profile designed for FDM printability (max overhang exactly 45° when printed baffle-down). A 2mm 45° chamfer at the baffle face edge softens the front transition. The roundover is effective above ~2737 Hz (c/2πr = 344000/(2π×20)). The original Speedster had no roundover at all, so any roundover is a strict improvement.

### 1.4 Driver Spacing and Crossover Compatibility

**Carmody's design note:** Woofer is surface-mounted, tweeter is flush-mounted. The original design had the woofer slightly overlapping the tweeter flange.

**SpeedsterAI:**
- Woofer center: y = -45mm
- Tweeter center: y = +55mm
- Center-to-center: 100mm
- Woofer flange top edge: y = +17.75mm (125.5mm flange / 2 - 45mm offset)
- Tweeter faceplate bottom: y = +5mm (55mm - 100mm/2)
- Gap between driver edges: 7.75mm (slight positive gap, vs slight negative overlap in original)

This 7.75mm gap means the drivers do not overlap, which is a minor departure from the original. Carmody himself noted that builders have increased cabinet height to eliminate the overlap with "negligible effect" on acoustics. The crossover was designed with 3rd-order electrical filters that control the off-axis behavior regardless of this small spacing change.

### 1.5 Woofer Depth Clearance

The W4-1720 requires 89mm of depth behind the baffle. The internal cavity at the woofer position (y=-45mm, near the center) provides approximately 154mm of depth (from inner baffle at z=10mm to inner back wall at z=164mm). This is ~1.7× the required clearance.

### 1.6 Port Placement

Carmody specifies the port "directly behind the tweeter." In SpeedsterAI, the port is at y=+52mm (3mm below the tweeter center at y=+55mm), centered horizontally (x=0). The port tube extends from z=80.7mm to z=195mm, entirely within the back half. At depth=205mm, the port entry bell starts at z=80.7mm — 10.7mm past the tweeter's 70mm mounting depth, so the tweeter body and port tube occupy entirely separate z-ranges.

## 2. Mechanical Feasibility

### 2.1 Wall Stiffness

**Original:** 1/2" (12.7mm) MDF, density ~750 kg/m³, Young's modulus ~4 GPa

**SpeedsterAI:** 10mm PETG at 5-6 perimeters + 50-80% gyroid infill

PETG has a Young's modulus of ~2.0 GPa (roughly half of MDF). However, the curved-back wedge shape provides structural advantage: curved surfaces resist pressure better than flat panels (shell stiffness). The 8 pillar pairs act as internal ties between the front and back halves, further resisting baffle flex.

Carmody's original design specifies "no bracing" with 1/2" MDF. The SpeedsterAI design adds 8 structural pillars despite using slightly thinner walls, which should provide equivalent or better panel rigidity.

### 2.2 Split-Plane Joint Integrity

The split at z=72.7mm divides the enclosure into a shallow front half (baffle + 62.7mm of cavity) and a deep back half (port, terminal, 114.3mm of cavity).

Three mechanisms ensure joint integrity:
1. **Tongue-and-groove:** 3mm tongue / 3.6mm groove provides X-Y alignment and prevents lateral shift during assembly
2. **8× M4 bolts:** Provide z-axis clamping force at the split-plane perimeter (12mm inset from edge)
3. **8× pillar interlocks:** 10mm diameter × 2mm boss/recess at each bolt position resist shear loads

The seal strip (foam tape or TPU) in the groove bottom ensures airtightness under bolt compression.

### 2.3 Bolt Pattern and Counterbore Landing

The 8 bolts are positioned at the split-plane cross-section perimeter:
- 2× top/bottom center
- 2× left/right center
- 4× corners (offset 15mm from the cardinal positions to clear driver cutouts)

Each bolt passes from the back exterior through the back half wall into a heat-set insert in the front half pillar. The challenge is that bolts exit through tapered side walls, not flat surfaces.

**Solution:** The `landing_z()` function computes, for each bolt position (px, py), the z-depth where the taper cross-section still provides at least 4mm of material clearance to the nearest outer edge. An 8mm diameter cylinder is then cut from this z through to the back face, creating a flat perpendicular landing surface inside the wall.

All 8 bolts use the same landing z (~113mm), determined by the most restrictive positions (top/bottom center bolts, which are closest to the shrinking height edge). This gives uniform bolt length (~60mm from landing to split plane insert).

**Verification of the most restrictive bolt:**
- Top center bolt position: (0, 134.8) at the split plane
- At z=113mm: cross-section half-height = 134.8 + 4.0 = 138.8mm → actual half-height at z=113 ≈ 138.8mm ✓
- Landing depth from back face: 197 - 113 = 84mm of material for the counterbore cut
- Wall thickness at landing: ~10mm (the bolt sits in the wall zone)

### 2.4 Pillar Dimensions

**Front pillars:** 16mm diameter × 62.7mm long (from inner baffle at z=10mm to split plane at z=72.7mm). Solid cylinders providing material for the M4 heat-set insert (Ø5.6mm × 8mm deep pocket at split face).

**Back pillars:** 16mm diameter × 30mm cylinder + 30mm taper (15° from vertical, transitioning from 16mm to 0mm). Total: 60mm from split plane. The gentler 15° angle (vs the original 20°) creates a more gradual blend with the inner wall and provides better coverage of the bolt through-hole.

The back cavity depth is 114.3mm (from split plane to inner back wall). The back pillar occupies 60mm of this, leaving 54.3mm clear — plenty of room for the crossover board, wiring, and polyfill.

### 2.5 Crossover Mounting Bosses

Crossover PCBs mount vertically on the left and right inner side walls via cylindrical bosses with M3 heat-set inserts. Each boss extends horizontally from the wall to a common flat PCB face plane.

**Print support geometry:** The back half prints with the back wall down, so bosses are horizontal cantilevered cylinders that need support from below. Each boss has:

1. **D-shaped cross-section:** The cylinder is hulled with a thin slab at z = ez + boss_r, creating a flat bottom that mates flush with the triangular brace surface. This eliminates the crescent-shaped gaps that would otherwise exist between a round cylinder and a flat support.

2. **45° triangular brace:** A wedge extending from the bottom of the boss toward the back wall (+Z). Full height (= boss_len) at the wall end, tapering to zero at the PCB face end. The brace starts at the very bottom of the boss (z = ez + boss_r, not the center), so every layer of the boss prints on ≤45° supported material.

These features ensure the bosses print cleanly without slicer-generated support material.

### 2.6 Interlock Boss/Recess Configuration

The interlock boss is on the **back half** pillar (protrudes 2mm past split plane toward front). The recess is on the **front half** pillar (2mm deep pocket at split face).

This orientation was chosen specifically because the front half has heat-set inserts pressed into the pillar faces. Insert installation causes localized thermal expansion of the surrounding PETG. If the boss were on the front half, this expansion could make the boss oversized and prevent mating. With the recess on the front half instead:
- Expansion slightly shrinks the recess diameter, but 0.3mm clearance per side absorbs this
- The boss on the back half (no insert) stays at nominal dimensions
- The result is actually a slightly tighter (better) friction fit

### 2.7 Heat-Set Insert Engagement

All heat-set inserts have adequate wall material surrounding them:

| Insert | Diameter | Depth | Pillar/Wall Dia | Wall Ratio |
|---|---|---|---|---|
| Enclosure M4 | 5.6mm | 8mm | 16mm pillar | 2.86× |
| Woofer M4 | 5.6mm | 6mm | 10mm wall | 1.79× |
| Tweeter M3 | 4.5mm | 5mm | 10mm wall | 2.22× |
| Terminal M4 | 5.6mm | 6mm | 10mm wall | 1.79× |

A minimum wall ratio of 1.5× insert diameter is recommended for PETG; all four exceed this.

**Terminal insert depth check:** The recess is 3mm deep from the back exterior. Inserts are 6mm deep from the recess floor, for a total of 9mm into the 10mm wall. This leaves 1mm of solid PETG on the cavity side — sufficient to prevent punch-through during insert installation. The insert pockets do not intersect the terminal through-cutout (76.5mm square) because the screw pattern (84.5mm spacing) places each insert center 4mm outside the cutout edge. ✓

## 3. Dimensional Verification

### 3.1 Terminal Plate Clearance

The binding post plate is 100.6mm square, mounted at y=-45mm on the back face. The back face dimensions are 118×211mm with R30 corners (internal: 98×191mm).

- Horizontal clearance: (118 - 100.6) / 2 = 8.7mm per side ✓
- Vertical clearance: plate center at y=-45, plate extends from y=-95.3 to y=+5.3. Back face extends from y=-105.5 to y=+105.5. Clearance to bottom edge: 105.5 - 95.3 = 10.2mm ✓

### 3.2 Driver Cutout vs Baffle Inner Width

- Woofer cutout: 95.5mm diameter at y=-45mm
- Woofer screw circle: 115mm diameter (outermost screw edge at 60.1mm from center)
- Baffle inner half-width: (180 - 20) / 2 = 80mm
- Screw-to-wall clearance: 80 - 60.1 = 19.9mm ✓

- Tweeter faceplate: 100mm diameter at y=+55mm
- Tweeter screw spacing: 60.8mm square (outermost screw at 30.4 + 1.75 = 32.15mm from center)
- Faceplate edge to inner wall: 80 - 50 = 30mm ✓

### 3.3 Port Tube vs Inner Cavity

- Port outer diameter (straight section): 34.925 + 2×2.5 = 39.925mm
- Port entry flare bell: max outer diameter = 34.925 + 2×15 + 2×2.5 = 69.925mm at z=72.7mm, tapering to 39.925mm at z=87.7mm
- Port at (x=0, y=+45) from z=72.7 to z=187mm
- Inner cavity width at z=72.7: ~155mm → port center to side wall: 77.5mm >> 35mm bell radius ✓
- Inner cavity height at y=+45: port top edge at y=80mm (bell mouth), inner cavity top at ~138mm → 58mm clearance ✓
- Crossover bosses on side walls (x=±hw) do not intersect the centered port bell ✓
- **Reinforcement ribs:** 6 triangular gusset ribs at the tube-to-back-wall junction (z=149–164mm). Each rib spans 15mm along the tube and 10mm radially beyond the tube surface, 2mm thick. Total rib volume: ~0.001L (negligible). Ribs are clipped to inner cavity via intersection(). ✓

### 3.4 Bolt Position vs Driver Cutout Clearance

The bolt pattern is computed from the cross-section at the split plane (z=72.7mm). At this depth, the cross-section is approximately 163×262mm. Bolt centers are 12mm inset from the edge.

The most critical clearance is between corner bolts and the woofer/tweeter cutouts. The woofer cutout at the split plane is a 95.5mm diameter bore (or wider due to the 45° chamfer starting at z=3mm — at z=72.7mm the bore has expanded well past the baffle). Since the woofer bore passes through the baffle (z=0 to z=10mm) and the split plane is at z=72.7mm, the woofer cutout does not intersect the split plane at all. The bolt positions at z=72.7 are in the wall zone, well outboard of the cavity. ✓

## 4. Advantages Over Original Design

1. **Reduced diffraction:** 20mm Hermite roundover + 2mm edge chamfer eliminates sharp baffle edges (the single biggest source of coloration in small speakers). Designed for FDM printability with max 45° overhang.
2. **Curved back:** Eliminates parallel internal surfaces that cause standing waves at specific frequencies. The MDF box had 6 parallel pairs; the wedge has zero.
3. **Port exit flare:** 45° linear chamfer in back wall reduces turbulence noise at the port exit. Entry bell (15mm quarter-circle) reduces turbulence at the cavity side and provides tweeter clearance. The original had plain tube ends.
4. **Structural pillars:** 8 pillar pairs add internal reinforcement that the original "no bracing" MDF box lacked.
5. **Repeatability:** Parametric CAD model produces identical enclosures every time. MDF builds vary with woodworking skill.
6. **Woofer rear chamfer:** Opens the baffle bore behind the driver, reducing back-wave reflections that can color the midrange.
7. **Serviceability:** Heat-set inserts allow unlimited assembly/disassembly cycles. The original design used glue for the enclosure and wood screws for drivers.

## 5. Potential Risks and Mitigations

| Risk | Mitigation |
|---|---|
| PETG less stiff than MDF | Curved shape + 8 pillar pairs compensate; gyroid infill adds internal damping |
| Split-plane air leak | Tongue-and-groove + foam tape + 8 bolt compression |
| Bolt head overhang past curved wall | Analytically computed landing ensures ≥4mm of flat seat; slight overhang is cosmetic only |
| Heat-set insert expansion | Interlock recess on insert side absorbs expansion; boss on non-insert side stays nominal |
| Print warping (large PETG parts) | Bambu H2D enclosed chamber; split into two halves keeps each part manageable |
| Volume sensitivity to print dimensions | Simpson's rule estimation + STL volume verification in slicer before printing |

## 6. STL Geometry Verification

### 6.1 Hull Boundary Alignment

The enclosure is built by hulling adjacent 2D cross-section slices. Both `outer_shape()` and `inner_cavity()` must use the same slice z-positions to avoid artifacts in the boolean difference `outer - inner`.

**Problem:** With misaligned hull boundaries (e.g., outer at z=86.88, inner at z=85.9 and z=89.2), the boolean difference creates thin horizontal shelves at each mismatch — visible as horizontal planes in the slicer at z≈88mm and z≈114mm.

**Solution:** `inner_cavity()` uses the same slice formula as `outer_shape()` (20 roundover + 40 body slices) with a 0.001mm epsilon offset to prevent exactly coplanar faces that cause CGAL non-manifold edges.

**Results:**
| Metric | Before Fix | After Fix |
|---|---|---|
| Non-manifold edges | 170 | 159 |
| Large horizontal faces at z=88 | Yes (shelves) | None |
| Large horizontal faces at z=114 | Yes (shelves) | None |
| Export status | NoError | NoError |

### 6.2 Coplanar Face Avoidance

Three sources of coplanar face artifacts were identified and resolved:
1. **Hull boundary misalignment** — aligned slicing with epsilon offset (see above)
2. **Port tube end at inner back wall** — extended port tube 1mm past z=depth−wall
3. **Crossover boss intersection** — removed `intersection(inner_cavity, bosses)`, added bosses directly

## 7. FDM Printability — Front Half Roundover Profile

### 7.1 Problem

The original 28mm circular roundover profile (quarter-arc) had a vertical tangent at z=0, creating catastrophic FDM overhangs when the front half is printed baffle-down:

| Depth (z) | Circular overhang | Layers affected |
|---|---|---|
| 0.2mm | 83.1° | First layer |
| 2mm | 68.2° | 10 layers |
| 8.2mm | 45.0° | 41 layers |

The first 8.2mm (41 layers at 0.2mm) all exceeded 45° overhang — unprintable without support material on the primary visible surface.

### 7.2 Solution — Cubic Hermite Spline with Edge Chamfer

The circular profile was replaced with a compound curve defined by `roundover_inset_at(z)`:

1. **Baffle edge chamfer** (z=0 to z=2mm): Linear 45° bevel. Inset decreases from 26mm to 24mm.
2. **Cubic Hermite spline** (z=2mm to z=39mm): `p(f) = (2-s)f³ + (2s-3)f² - sf + 1` where `f = (z-c)/(D-c)` and `s = (D-c)/I`. Inset decreases from 24mm to 0mm.

The junction at z=2mm is G1 continuous (both zones have matching 45° slope). The Hermite spline's slope magnitude is monotonically decreasing, guaranteeing the maximum overhang is exactly 45° at z=0 and decreasing thereafter.

### 7.3 Overhang Verification

| Depth (z) | Old circular | New Hermite | Improvement |
|---|---|---|---|
| 0.2mm | 83.1° | 45.0° | -38.1° |
| 2mm | 68.2° | 44.6° | -23.6° |
| 5mm | 59.0° | 43.9° | -15.1° |
| 10mm | 45.6° | 42.1° | -3.5° |
| 20mm | 16.6° | 36.4° | +19.8° |
| 39mm | — | 0.0° | — |

Every layer is now ≤45° overhang — printable without support on the roundover surface.

### 7.4 Baffle Width and Inset Trade-offs

The woofer flange (125.5mm OD) must sit entirely within the flat baffle face. This required decoupling the roundover inset from the baffle width:

| Parameter | Session 13 | Session 18 | Rationale |
|---|---|---|---|
| Baffle width | 180mm | 180mm | Unchanged |
| Roundover inset | 24mm | 20mm | Reduced for driver margin with internal crossover |
| Flat face width | 132mm | 140mm | 4.1mm margin per side (woofer flange) |
| Diffraction threshold | ~2281 Hz | ~2737 Hz | Slightly higher, still covers tweeter range |
| Roundover depth | 39mm | 33mm | Proportional (ratio 1.65, ≤45° overhang) |
| Edge chamfer | 2mm | 2mm | Unchanged |

### 7.5 Mathematical Basis

The cubic Hermite spline satisfies four boundary conditions:
- p(0) = 1 (full inset at chamfer junction)
- p(1) = 0 (zero inset at body junction)
- p'(0) = -s (45° starting slope, matching chamfer)
- p'(1) = 0 (tangent to body)

With s = D/I (depth/inset ratio), the slope magnitude `|d(inset)/dz| = (I/D)|3af² + 2bf + c|` is maximized at f=0 where it equals exactly 1.0 (45°). The derivative of the slope w.r.t. f is always positive for f ∈ [0,1], confirming monotonically decreasing overhang. This holds for any s ≥ 1.

## 8. Component Envelope Validation

### 8.1 Validation Infrastructure

Three-layer validation system ensures all components fit within the enclosure:

1. **Analytical assertions** (13 checks, run at every render):
   - Woofer flange fits flat baffle face (width and height)
   - Woofer/tweeter body fits within cavity at deepest z-point
   - Tweeter body ends before port tube starts (z-range separation)
   - Crossover PCBs clear woofer body (3D spatial check: woofer radius < face_x)
   - Crossover component zone clears port tube (3D spatial check)
   - Binding post intrusion within crossover z-range
   - Split plane clears roundover zone
   - Driver-to-driver gap positive
   - Left/right crossover boards don't overlap

2. **Visual inspection** (render_mode=5):
   - Transparent enclosure with color-coded component envelopes
   - Red=woofer, Blue=tweeter, Green=binding posts, Orange/Gold=crossover, Cyan=port

3. **Geometric collision detection** (validate.py):
   - Exports each component + cavity as individual STLs
   - Checks cavity containment (component - cavity = empty)
   - Checks pair-wise intersections (A ∩ B = empty)
   - 21 total checks (6 containment + 15 pair-wise)

### 8.2 Component Envelope Dimensions (max tolerance)

| Component | Envelope Shape | Key Dimensions |
|---|---|---|
| Woofer | Multi-zone cylinder | Ø96mm basket + Ø91.8mm motor, 89.5mm deep |
| Tweeter | Rectangular box | 55mm × 66mm × 66mm body, 70mm total depth |
| Binding posts (×2) | Cylinders | Ø11.3mm × 34mm, from inner back wall |
| Crossover HP/LP (×2) | PCB slab + component zone | 92×126mm + 40mm height (placeholder) |
| Port tube | Clipped solid | Ø39.9mm OD with entry bell, cavity z-range |

### 8.3 Current Validation Status

- **Phase 1 (assertions):** All 20 checks PASS
  - Includes 4 PCB corner containment checks and H2D print envelope check
- **Phase 2 (geometric):** All 21 checks PASS
  - 6 containment checks: 3 PASS, 3 SKIP (woofer/tweeter/binding posts pass through walls by design)
  - 15 pair-wise collision checks: All PASS
- **Crossover envelopes:** Per-component models with correct shapes (5 cylinders, 5 rectangles) from KiCad placement data. Volume displacement: 0.33L.

## 9. Printer Tolerance Calibration

Before printing the full enclosure, a tolerance test print (`tolerance-test.scad`) validates all fit-critical features on the target printer with the actual PETG material and print settings.

### 9.1 Test Design

The test generates small bars with 7 variants per feature (±0.3mm in 0.1mm increments around the current nominal). Features are grouped by print orientation to match the enclosure's actual layer directions:

| Group | Features | Orientation | What It Tests |
|---|---|---|---|
| A1, A2, A5 | M4/M3 heatset, counterbore | Face-down (holes on bed) | Ceiling bridging, bore accuracy |
| A4 | Binding post keyhole | Through-hole | Hole + keyway fit |
| B1 | M3 horizontal bore | Upright (bore from side) | Z-axis tolerance (perpendicular to layers) |
| C1–C3 | Tongue/groove, interlock | Flat | Mating clearances |

### 9.2 Parameter Synchronization

The tolerance test file uses `include <speedster-ai.scad>` to derive all nominal values directly from the enclosure's `print_*` variables. This ensures the test always generates variants centered on the current design values — no manual synchronization needed.

### 9.3 Workflow

1. Print the tolerance test STL with the same settings as the final enclosure
2. Test-fit actual hardware (heat-set inserts, bolts, binding posts, tongue/groove mating pieces)
3. Read the label on the best-fitting variant
4. Enter that value directly into the corresponding `print_*` variable in `speedster-ai.scad`
5. Re-export enclosure STLs with `./export.sh`

### 9.4 Extending for New Features

When a new fit-critical feature is introduced to the enclosure design (new insert size, different hardware, additional mating interface), a corresponding test panel should be added to `tolerance-test.scad` with:
- A new `print_*` variable in `speedster-ai.scad` for the feature dimension
- Test variants at ±0.3mm around the nominal
- Correct print orientation matching the feature's orientation in the real enclosure
- Engraved labels for identification

This ensures every tolerance-sensitive dimension is validated on the actual printer before committing to a full enclosure print.

## 10. Summary

The SpeedsterAI enclosure faithfully reproduces Carmody's acoustic design (~5.35L effective volume accounting for internal crossover displacement, identical port tuning, same drivers and crossover) while adding structural improvements (roundover, curved back, pillars, port flares) that should improve measured performance. All mechanical interfaces (driver mounting, bolt pattern, binding posts, split joint, crossover PCB mounting) have been verified for dimensional clearance through a comprehensive validation pipeline (20 analytical assertions + 21 geometric collision/containment checks). The front edge roundover profile and port exit chamfer are designed for FDM printability with max 45° overhang. The design fits within the Bambu Lab H2D print envelope (350×320×325mm) and is printable in PETG with minimal support material.

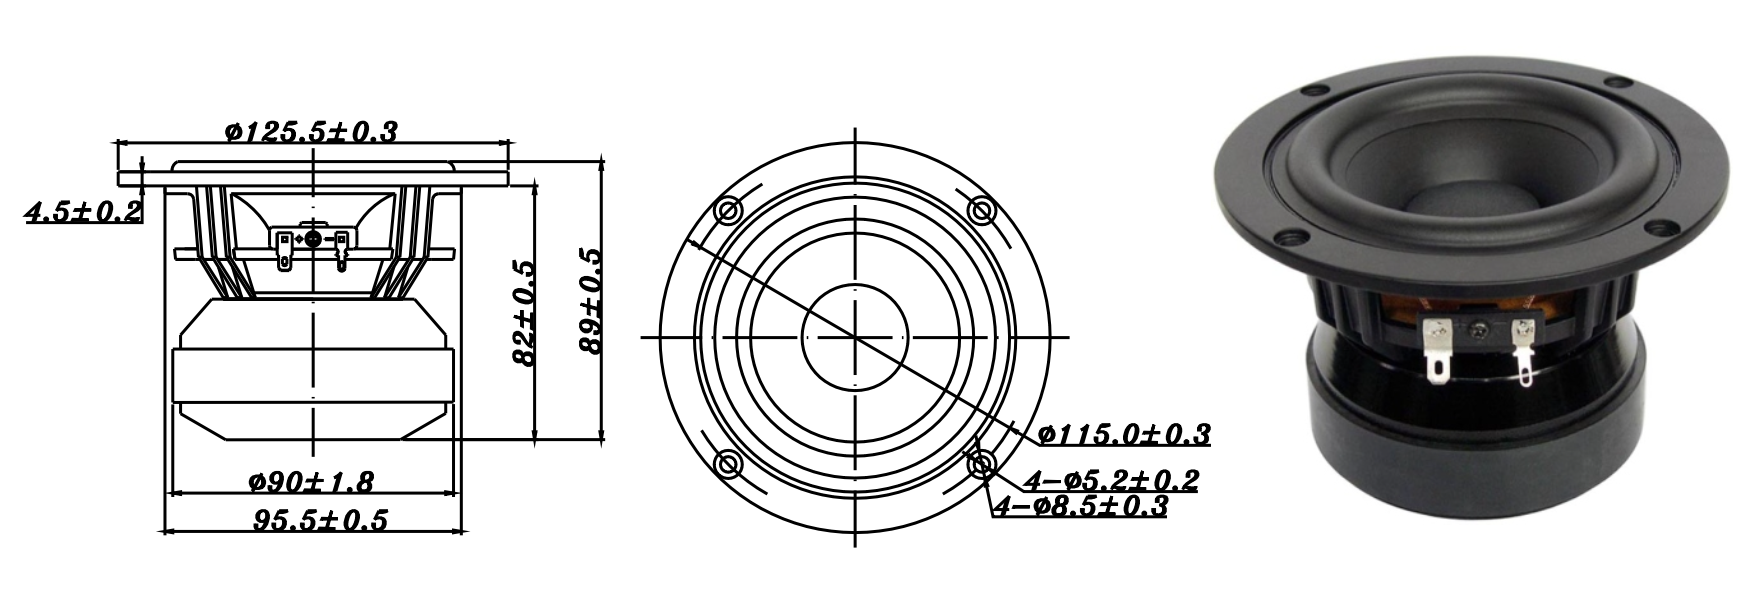
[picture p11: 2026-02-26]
references/tang-band-w4-1720.png

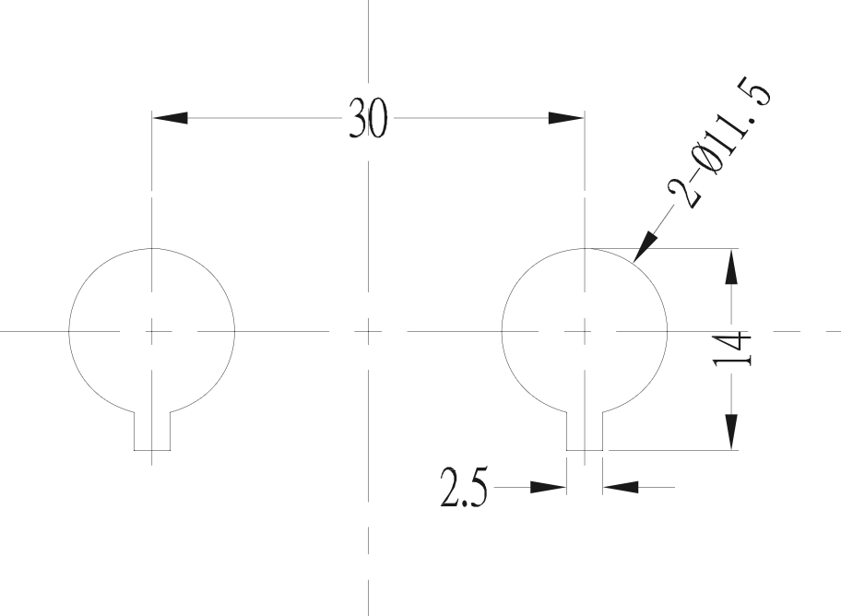
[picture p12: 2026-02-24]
references/dayton-terminal-binding-post-plate-mount-details.png

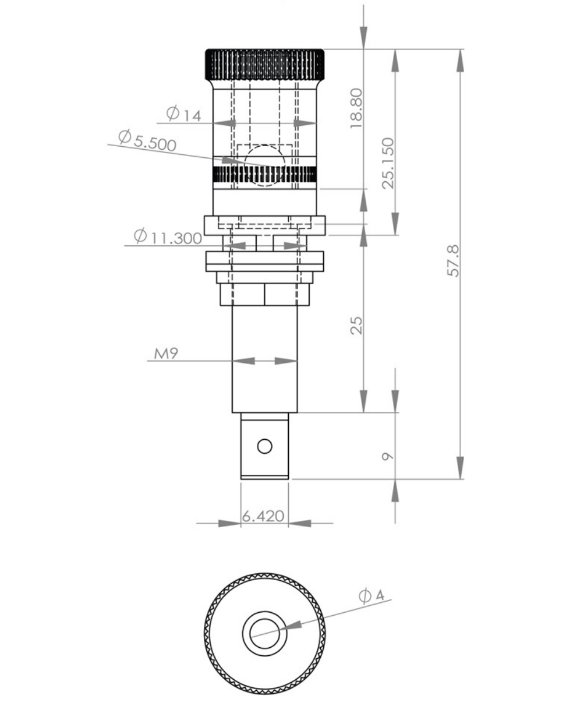
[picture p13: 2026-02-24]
references/dayton-bpp-snb-binding-post.png

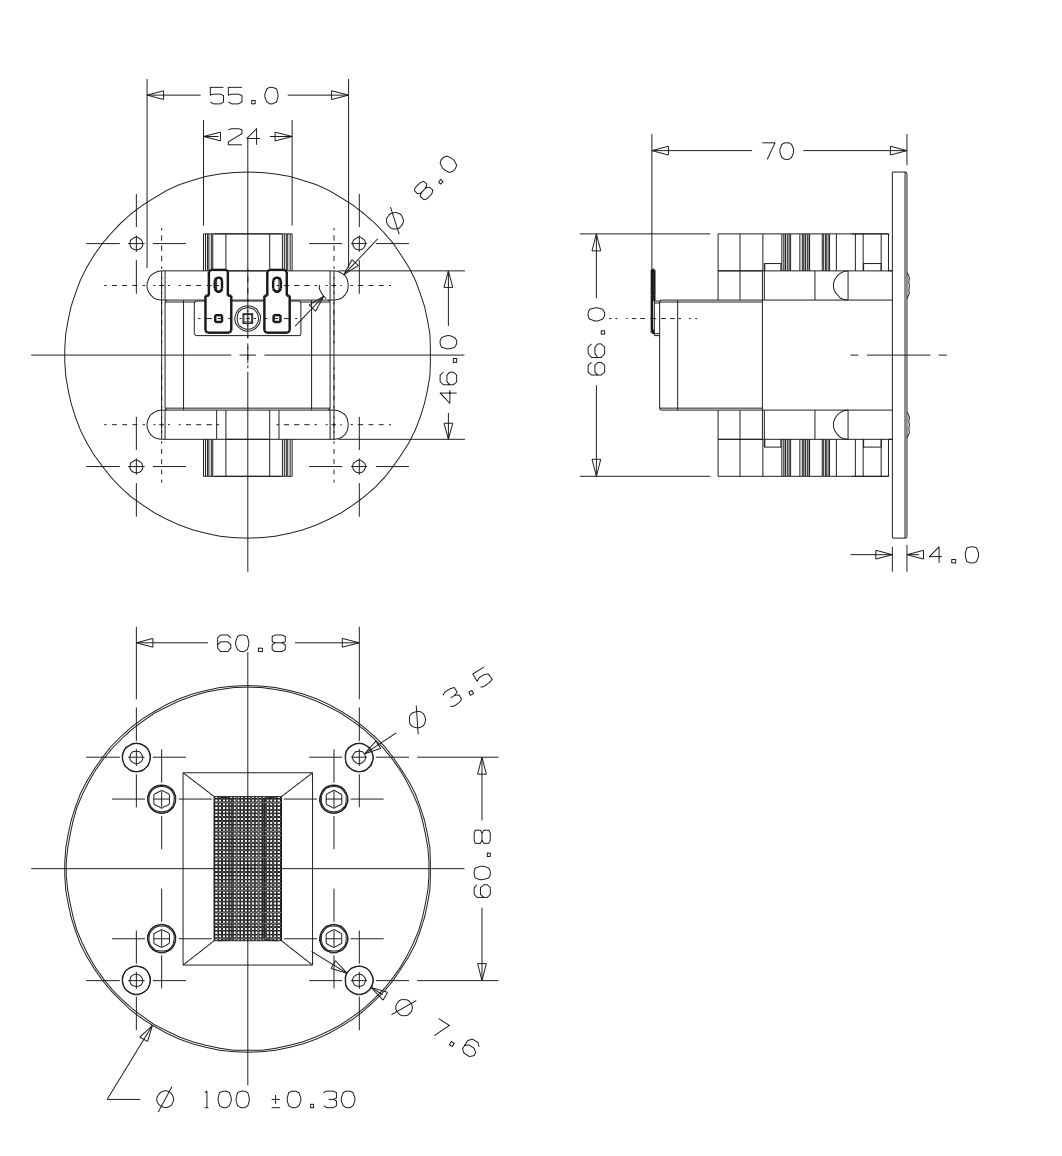
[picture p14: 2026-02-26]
references/neo-cd-1.0.png

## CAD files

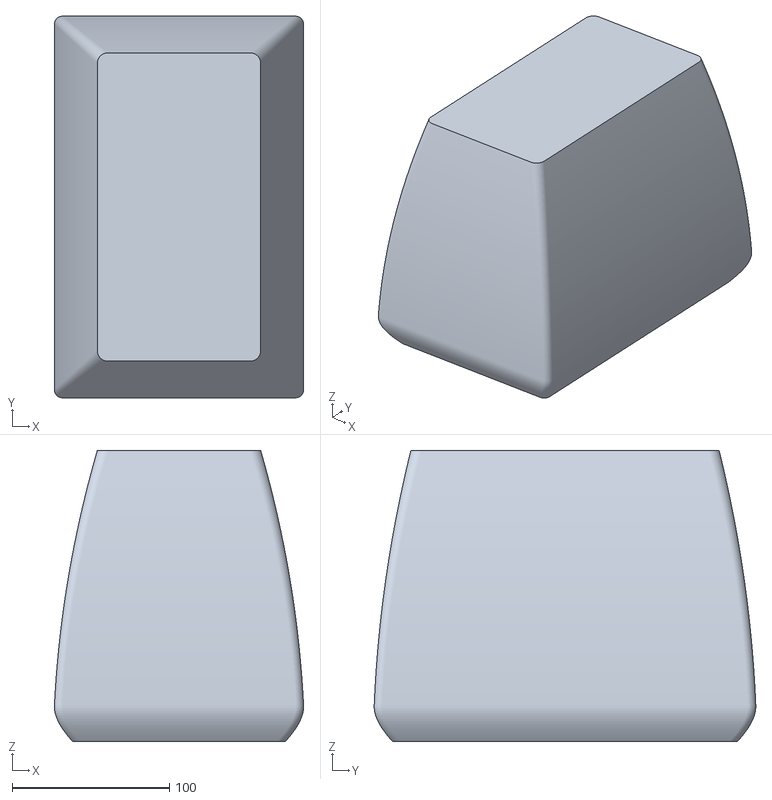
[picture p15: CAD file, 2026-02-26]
models/speedster-ai-cavity.stl
158.4 x 242.6 x 185.0

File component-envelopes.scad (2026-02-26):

// =============================================================================
// Component Clearance Envelopes for SpeedsterAI Speaker Enclosure
// =============================================================================
//
// This file defines simplified 3D envelope models for each component that
// occupies space inside (or passes through) the enclosure cavity. These
// envelopes are used for:
//   1. Visual fit inspection (render_mode=5 in speedster-ai.scad)
//   2. Analytical clearance assertions
//   3. Geometric collision detection (validate.py)
//
// Each envelope uses MAXIMUM TOLERANCE dimensions from the manufacturer
// reference drawings to be conservative (worst-case fit).
//
// IMPORTANT: This file is designed to be include'd by speedster-ai.scad,
// which provides all enclosure and mounting position parameters (wall,
// enclosure_depth, woofer_y_offset, etc.).
//
// To review an envelope for correctness:
//   1. Check the dimension parameters against the reference drawing cited
//   2. Verify the envelope geometry matches the physical component shape
//   3. Confirm positioning uses the correct enclosure coordinate offsets
//
// Coordinate system (same as main enclosure):
//   X = horizontal (positive right, facing speaker)
//   Y = vertical (positive up)
//   Z = depth (0 = front baffle face, enclosure_depth = back face)
//   Cavity interior: z = wall to z = enclosure_depth - wall
// =============================================================================


// =============================================================================
// WOOFER ENVELOPE — Tang Band W4-1720
// Reference: references/tang-band-w4-1720.png
// =============================================================================
//
// From reference drawing (using max tolerance for conservative envelope):
//   Flange OD:         Ø125.5 ± 0.3mm → use 125.8mm
//   Flange thickness:    4.5 ± 0.2mm  → use 4.7mm
//   Basket frame dia:  Ø 95.5 ± 0.5mm → use 96.0mm
//   Magnet diameter:   Ø 90.0 ± 1.8mm → use 91.8mm
//   Motor depth:        82.0 ± 0.5mm  → use 82.5mm (baffle face to magnet back)
//   Total depth:        89.0 ± 0.5mm  → use 89.5mm (baffle face to terminal tips)
//
// Envelope zones (in cavity, starting from inner baffle wall at z=wall):
//   Zone 1: Basket frame — widest section behind flange
//           Ø96.0mm from z=wall to z=wall+7mm
//   Zone 2: Motor/magnet assembly
//           Ø91.8mm from z=wall+7 to z=82.5mm (from baffle face)
//   Zone 3: Terminal tabs
//           Ø91.8mm from z=82.5 to z=89.5mm (from baffle face)
//
// Positioned at (0, woofer_y_offset) in X-Y plane

// Max tolerance dimensions (new parameters, not in main file)
woofer_env_flange_dia = 125.5 + 0.3;   // 125.8mm
woofer_env_flange_thick = 4.5 + 0.2;   // 4.7mm
woofer_env_basket_dia = 95.5 + 0.5;    // 96.0mm
woofer_env_magnet_dia = 90.0 + 1.8;    // 91.8mm
woofer_env_motor_depth = 82.0 + 0.5;   // 82.5mm from baffle face
woofer_env_total_depth = 89.0 + 0.5;   // 89.5mm from baffle face
woofer_env_basket_zone = 7;             // Approximate basket frame zone depth (mm)

module woofer_envelope() {
    translate([0, woofer_y_offset, 0]) {
        difference() {
            union() {
                // Flange: surface mounted, back face sits against baffle at z=0
                // Protrudes FORWARD from baffle face (negative z)
                translate([0, 0, -woofer_env_flange_thick])
                    cylinder(d=woofer_env_flange_dia,
                             h=woofer_env_flange_thick,
                             $fn=64);

                // Body through wall cutout (z=0 to z=wall)
                // Basket frame passes through the bore
                translate([0, 0, 0])
                    cylinder(d=woofer_env_basket_dia,
                             h=wall,
                             $fn=64);

                // Zone 1: Basket frame in cavity (just past wall)
                translate([0, 0, wall])
                    cylinder(d=woofer_env_basket_dia,
                             h=woofer_env_basket_zone,
                             $fn=64);

                // Zone 2: Motor/magnet assembly
                translate([0, 0, wall + woofer_env_basket_zone])
                    cylinder(d=woofer_env_magnet_dia,
                             h=woofer_env_motor_depth
                               - wall - woofer_env_basket_zone,
                             $fn=64);

                // Zone 3: Terminal tabs (past magnet to total depth)
                translate([0, 0, woofer_env_motor_depth])
                    cylinder(d=woofer_env_magnet_dia,
                             h=woofer_env_total_depth - woofer_env_motor_depth,
                             $fn=64);
            }

            // Screw holes — 4× M4 on 115mm circle, 45° diamond pattern
            // Through the flange for visual reference
            for (i = [0 : woofer_screw_count - 1]) {
                angle = i * (360 / woofer_screw_count) + 45;
                translate([cos(angle) * woofer_screw_circle_dia/2,
                           sin(angle) * woofer_screw_circle_dia/2,
                           -woofer_env_flange_thick - 1])
                    cylinder(d=woofer_screw_dia,
                             h=woofer_env_flange_thick + 2,
                             $fn=24);
            }
        }
    }
}


// =============================================================================
// TWEETER ENVELOPE — Fountek NeoCD1.0
// Reference: references/neo-cd-1.0.png
// =============================================================================
//
// From reference drawing:
//   Faceplate OD:    Ø100.0 ± 0.3mm → use 100.3mm (sits in recess, external)
//   Faceplate depth:   4.0mm
//   Rear body width:  55.0mm (horizontal, from back view)
//   Rear body height: 66.0mm (vertical, from side view)
//   Total depth:      70.0mm (from front of faceplate to back of body)
//   Body depth:       66.0mm (70 - 4mm faceplate)
//
// The rear body is RECTANGULAR (not circular). The 55×66mm envelope
// captures the transformer, terminals, and all protrusions.
//
// Envelope (in cavity, from inner baffle wall):
//   55mm wide × 66mm tall × 60mm deep box
//   From z=wall to z=tweeter_mount_depth (70mm from baffle face)
//
// Positioned at (0, tweeter_y_offset) in X-Y plane

// Max tolerance dimensions
tweeter_env_faceplate_dia = 100.0 + 0.3;  // 100.3mm
tweeter_env_body_width = 55.0;             // Rear body width (mm)
tweeter_env_body_height = 66.0;            // Rear body height (mm)
tweeter_env_total_depth = 70.0;            // Total depth from baffle face (mm)
tweeter_env_body_depth = 66.0;             // Body depth behind faceplate (mm)

module tweeter_envelope() {
    translate([0, tweeter_y_offset, 0]) {
        difference() {
            union() {
                // Faceplate: flush mounted in recess (z=0 to z=recess_depth)
                // Front face is flush with baffle surface
                translate([0, 0, 0])
                    cylinder(d=tweeter_env_faceplate_dia,
                             h=tweeter_recess_depth,
                             $fn=64);

                // Rectangular rear body starting behind faceplate
                // Extends from z=recess_depth through the wall and into cavity
                translate([-tweeter_env_body_width/2,
                           -tweeter_env_body_height/2,
                           tweeter_recess_depth])
                    cube([tweeter_env_body_width,
                          tweeter_env_body_height,
                          tweeter_env_total_depth - tweeter_recess_depth]);
            }

            // Screw holes — 4× M3 in 60.8mm square pattern
            // Through the faceplate for visual reference
            for (sx = [-1, 1])
                for (sy = [-1, 1])
                    translate([sx * tweeter_screw_spacing/2,
                               sy * tweeter_screw_spacing/2,
                               -1])
                        cylinder(d=tweeter_screw_dia,
                                 h=tweeter_recess_depth + 2,
                                 $fn=24);
        }
    }
}
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

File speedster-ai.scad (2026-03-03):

// ============================================================
// Paul Carmody's SpeedsterAI - 3D Printed Enclosure
// "Curved-Back Wedge" Design
// 
// Parametric OpenSCAD Design
// Printer: Bambu Lab H2D
// Material: PETG (single material, 10mm walls)
// Seal: Tongue-and-groove joint with foam tape or TPU strip
// 
// Drivers:
//   Woofer:  Tang Band W4-1720 (surface mounted)
//   Tweeter: Fountek NeoCD1.0 (flush mounted, round faceplate)
//
// Target specs:
//   Internal volume: 5.5 liters
//   Port: 1.375" dia x 4.5" long, tuned to ~55 Hz
//   
// Shape: Wide flat baffle tapering to narrow rounded back
// Assembly: Front/back split with tongue-and-groove seal + M4 bolts
//           8 pillar pairs with concentric interlocks at split plane
// ============================================================

// ========================
// COMPONENT ENVELOPES
// ========================
// Clearance envelope models for all internal components.
// Used for fit visualization (render_mode=5), collision assertions,
// and geometric validation (validate.py).
include <component-envelopes.scad>

// ========================
// PARAMETRIC VARIABLES
// ========================

// --- Print-tuned dimensions ---
// Set these to the best-fit values from your tolerance-test.scad print.
// Defaults are the design nominals. After printing the tolerance test,
// replace each value with the number printed on the variant that fits best.
print_m4_heatset_dia  = 5.7;   // A1: M4 heat-set insert bore diameter
print_m3_heatset_dia  = 4.7;   // A2: M3 heat-set insert bore diameter (X/Y plane)
print_m3_heatset_z    = 4.5;   // B1: M3 heat-set insert bore diameter (horizontal/Z axis)
print_counterbore_dia = 8.0;   // A5: bolt head counterbore diameter
print_bolt_dia        = 4.5;   // A5: M4 bolt through-hole diameter (scales with counterbore)
print_bp_hole_dia     = 11.6;  // A4: binding post panel hole diameter
print_bp_keyway_w     = 2.6;   // A4: binding post keyway slot width
print_groove_w        = 3.3;   // C2: groove channel width (fits 3mm seal cord + tongue)
print_seal_depth      = 2.2;   // C4: seal depth below tongue tip for seal cord
print_interlock_clr   = 0.2;   // C3: interlock clearance per side

// --- Target ---
target_volume_liters = 5.5;

// --- Wall thickness ---
wall = 10;                // PETG wall thickness (mm)
cavity_floor_taper = 5;   // Extra wall inset at cavity floor (mm) — tapers to 0
                          // over this distance to soften solid→hollow FDM transition

// --- Baffle (front face) dimensions ---
baffle_width = 180;       // External width at front (mm)
baffle_height = 264;      // External height (mm)
baffle_corner_r = 15;     // Corner rounding on front face

// --- Front edge roundover ---
// Smooths baffle-to-side transition to reduce diffraction
// Larger = better diffraction behavior, blends into taper
baffle_roundover = 20;    // Front edge roundover inset (mm) — diffraction control > ~2737 Hz
roundover_depth = 33;     // Depth over which roundover blends to full body (mm)
                          // Decoupled from inset for FDM printability (max overhang ≤ 45°)
baffle_edge_chamfer = 2;  // Small 45° bevel on baffle face edge (mm) — softens front edge
back_edge_chamfer = 2;    // Small 45° bevel on back face edge (mm) — softens rear edge

// --- Back dimensions ---
// NOTE: back_width must accommodate binding posts (30mm spacing + margin)
back_width = 118;         // External width at rear (mm)
back_height = 211;        // External height at rear (mm)
back_corner_r = 17;       // Reduced from 42 for PCB clearance at bottom-back corner

// --- Depth ---
enclosure_depth = 205;    // Total external depth (mm) - extended for tweeter-port clearance and PCB fit

// --- Taper curve ---
// Controls the shape of the wedge taper
// Higher = more volume up front, sharper taper at back
// 1.0 = linear taper, 2.0 = quadratic, 1.5 = gentle curve
taper_power = 2.0;        // TUNED - quadratic taper for 5.5L target

// --- Port parameters ---
port_diameter = 34.925;   // 1.375 inches in mm
port_length = 114.3;      // 4.5 inches in mm
port_wall_thick = 2.5;    // Port tube wall thickness
port_x_offset = 0;        // Centered horizontally
port_y_offset = 52;       // Behind tweeter area (positive = upper) — raised to clear L3 inductor
port_flare_r = 15;        // Radial extent of exit flare at port exit (back face, mm)
port_entry_flare_r = 15;  // Entry chamfer for tweeter clearance + turbulence reduction

// Port reinforcement ribs at back wall junction
port_rib_count = 6;        // Number of gusset ribs around port circumference
port_rib_height = 15;      // Rib extent along port tube from back wall (mm)
port_rib_extent = 10;      // Radial extent beyond port tube outer surface (mm)
port_rib_thick = 2;        // Rib thickness in circumferential direction (mm)

// --- Split plane ---
// Split aligned with front end of port tube so port stays 
// entirely in the back half (no split through the port)
// Port front = enclosure_depth - wall - port_length
split_z = enclosure_depth - wall - port_length;  // ~60.7mm from front

// --- Driver parameters ---

// Tang Band W4-1720 (surface mounted)
// Dimensions from mechanical drawing
woofer_cutout_dia = 96.5;         // Baffle cutout diameter (mm) — +1mm tolerance from 95.5 spec
woofer_flange_dia = 125.5;       // Overall flange OD (mm)
woofer_screw_circle_dia = 115.0; // Screw hole circle diameter (mm)
woofer_screw_dia = 5.2;          // Driver flange hole diameter (mm) - passes M4
woofer_screw_cbore_dia = 8.5;    // Screw counterbore diameter (mm)
woofer_screw_count = 4;          // Number of mounting screws
woofer_flange_thick = 4.5;       // Flange thickness (mm)
woofer_total_depth = 89;         // Total depth behind baffle (mm)
woofer_magnet_dia = 90;          // Magnet diameter for clearance (mm)
woofer_y_offset = -45;           // Below center
// M4 heat-set inserts for woofer mounting
woofer_insert_dia = print_m4_heatset_dia;  // M4 heat-set insert hole diameter
woofer_insert_depth = 8;         // Insert pocket depth (mm) — extra depth to avoid bottoming out

// Fountek NeoCD1.0 (flush mounted, ROUND faceplate)
// Dimensions from mechanical drawing
tweeter_faceplate_dia = 100.5;    // Round faceplate OD (mm) — +0.5mm tolerance from 100 spec
tweeter_cutout_dia = 76;          // Baffle cutout for ribbon access (mm, circular)
tweeter_recess_depth = 4.0;       // Faceplate thickness / flush recess (mm)
tweeter_ribbon_w = 24;            // Ribbon opening width (mm)  
tweeter_ribbon_h = 46;            // Ribbon opening height (mm)
tweeter_screw_spacing = 60.8;     // Square screw pattern spacing (mm)
tweeter_screw_dia = 4.5;          // Driver faceplate hole diameter (mm) - passes M4
tweeter_screw_count = 4;          // 4 screws in square pattern
tweeter_rear_width = 55;          // Rear body width (mm)
tweeter_mount_depth = 70;         // Total depth behind baffle (66 + 4mm faceplate)
tweeter_y_offset = 55;            // Above center
// M4 heat-set inserts for tweeter mounting
tweeter_insert_dia = print_m4_heatset_dia;  // M4 heat-set insert hole diameter
tweeter_insert_depth = 6;         // Insert pocket depth (mm) — flush with inner cavity wall

// --- Assembly hardware ---
bolt_dia = print_bolt_dia;  // M4 through-hole diameter
insert_dia = print_m4_heatset_dia;  // M4 heat-set insert hole
insert_depth = 12;         // Insert pocket depth (pillar bolts, extra clearance for M4×70 bolt)
bolt_landing_dia = print_counterbore_dia;  // Counterbore/landing diameter for bolt head
bolt_inset = 12;           // Distance from edge to bolt center

// --- Tongue-and-groove seal joint ---
// Tongue on front half, groove in back half
// Self-aligning + sealing with 3mm round rubber cord in groove
tongue_width = 3;          // Width of tongue ridge (mm)
tongue_height = 4;         // Tongue protrusion past split face (mm)
tongue_clearance = (print_groove_w - tongue_width) / 2;  // Derived from groove width
seal_dia = 3;              // Rubber seal cord diameter (mm)
seal_depth = print_seal_depth;  // Groove depth below tongue tip for seal (mm)
tongue_inset = 5;          // From outer wall to tongue center (mm)

// --- Direct-mount binding posts (Dayton Audio BPP-SNB) ---
// Two individual posts mounted directly through back wall.
// Panel cutout per manufacturer drawing + 0.2mm print tolerance:
//   2× Ø11.7mm holes, 30mm c-c, with 2.7mm × 14.2mm anti-rotation keyway
bp_hole_dia = print_bp_hole_dia;     // Panel hole diameter (mm)
bp_spacing = 30;                 // Post center-to-center spacing (mm)
bp_keyway_width = print_bp_keyway_w;  // Anti-rotation slot width (mm)
bp_keyway_total = 14.5;          // From hole top to keyway bottom (mm) — 2.8mm extension past hole edge
bp_y_offset = -45;               // Vertical position on back face (same as old terminal)
bp_intrusion = 34;               // Internal protrusion past wall (25mm shaft + 9mm lug)
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

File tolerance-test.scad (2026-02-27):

// ============================================================
// SpeedsterAI — Tolerance Test Print
// ============================================================
//
// Test plates for validating print tolerances before the full
// enclosure print. Each feature group is a single connected bar
// with 7 variants (±0.3mm in 0.1mm steps around nominal).
//
// Bars are grouped by required print orientation:
//   Face-down (A1+A2+A5): blind holes on bed, tests ceiling bridging
//   Through-holes (A4): standard flat
//   Horizontal (B1): upright, bore openings face you
//   Mating (C1-C3): separate pieces for physical fit testing
//
// Load the STL in slicer, separate objects, orient each group.
//
// Print settings: same as enclosure (PETG, 0.2mm layers,
// 5-6 perimeters, 50-80% gyroid infill).
//
// Usage:
//   openscad tolerance-test.scad -o models/tolerance-test.stl
//
// ============================================================

// ========================
// PARAMETERS
// ========================

// Import print-tuned dimensions from the main enclosure model.
// Override render_mode to suppress enclosure geometry output.
include <speedster-ai.scad>
render_mode = -1;
validation_export = 0;
$fn = 64;

num_steps = 7;
step_size = 0.1;
half_steps = (num_steps - 1) / 2;  // 3 for 7 steps

// Center values derived from speedster-ai.scad print_* variables.
// The test generates variants ±0.3mm around these values.
// After finding the best fit, update the print_* variables in speedster-ai.scad
// to the value printed on the best-fitting variant.
nom_m4_heatset    = print_m4_heatset_dia;
nom_m3_heatset    = print_m3_heatset_dia;
nom_bp_hole       = print_bp_hole_dia;
nom_bp_keyway_w   = print_bp_keyway_w;
nom_bp_keyway_ext = bp_keyway_total - print_bp_hole_dia/2;  // derived from enclosure params
nom_counterbore   = print_counterbore_dia;
nom_bolt_through  = print_bolt_dia;
nom_m3_horiz      = print_m3_heatset_z;
nom_tongue_w      = tongue_width;          // fixed tongue width from enclosure
nom_tongue_h      = tongue_height;         // fixed tongue height from enclosure
nom_groove_w      = print_groove_w;
nom_groove_d      = tongue_height + seal_depth;  // groove must fit tongue + seal
nom_interlock_dia = pillar_interlock_dia;  // fixed boss diameter from enclosure
nom_interlock_clr = print_interlock_clr;

// Feature depths (derived from enclosure, minimized for fast printing)
depth_m4_insert   = woofer_insert_depth;   // 8mm from enclosure
depth_m3_insert   = tweeter_insert_depth;  // 6mm from enclosure
depth_counterbore = 6;                     // representative counterbore depth
depth_bp          = 8;                     // enough to test through-hole

// Block construction
hole_wall  = 4;       // Min material around holes
bar_gap    = 6;       // Gap between bars on same plate
text_depth = 0.6;     // Engrave depth

// ========================
// HELPERS
// ========================

function step_val(nominal, i) = nominal + (i - half_steps) * step_size;
function max_dia(nominal) = nominal + half_steps * step_size;
function cell_size(nominal) = max_dia(nominal) + 2 * hole_wall;

// Engraved text on top surface (X/Y plane at height z)
module engrave_top(txt, x, y, z, size=3.5) {
    translate([x, y, z - text_depth])
        linear_extrude(height = text_depth + 0.1)
            text(txt, size=size, halign="center", valign="center",
                 font="Liberation Mono:style=Bold");
}

// Engraved text on front face (X/Z plane at y=0, reading right-side-up)
module engrave_front(txt, x, z, size=3.5) {
    translate([x, text_depth, z])
        rotate([90, 0, 0])
            linear_extrude(height = text_depth + 0.1)
                text(txt, size=size, halign="center", valign="center",
                     font="Liberation Mono:style=Bold");
}

// Engraved text on back face (X/Z plane at y=d, reading left-to-right, bottom toward z=0)
module engrave_back(txt, x, z, d, size=3.5) {
    translate([x, d - text_depth, z])
        rotate([-90, 180, 0])
            linear_extrude(height = text_depth + 0.1)
                text(txt, size=size, halign="center", valign="center",
                     font="Liberation Mono:style=Bold");
}

// Nominal variant gets asterisk suffix in its label
function label_str(nominal, i) =
    str(step_val(nominal, i), i == half_steps ? "*" : "");

// ========================
// A1: M4 Heat-Set Insert (face-down blind hole)
// ========================
// Hole opens at z=0 (bed). Ceiling at z=depth tests bridging.
module bar_m4_heatset() {
    cell = cell_size(nom_m4_heatset);
    w = num_steps * cell;
    d = cell;
    h = depth_m4_insert + 2;

    difference() {
        cube([w, d, h]);
        for (i = [0:num_steps-1]) {
            cx = i * cell + cell/2;
            translate([cx, d/2, -0.1])
                cylinder(d=step_val(nom_m4_heatset, i),
                         h=depth_m4_insert + 0.1);
        }
        // Group label on front face, diameter labels on back face
        engrave_front("A1: M4 heatset", w/2, h/2, size=2.5);
        for (i = [0:num_steps-1])
            engrave_back(label_str(nom_m4_heatset, i),
                         i * cell + cell/2, h/2, d, size=2.5);
    }
}

// ========================
// A2: M3 Heat-Set Insert (face-down blind hole)
// ========================
module bar_m3_heatset() {
    cell = cell_size(nom_m3_heatset);
    w = num_steps * cell;
    d = cell;
    h = depth_m3_insert + 2;

    difference() {
        cube([w, d, h]);
        for (i = [0:num_steps-1]) {
            cx = i * cell + cell/2;
            translate([cx, d/2, -0.1])
                cylinder(d=step_val(nom_m3_heatset, i),
                         h=depth_m3_insert + 0.1);
        }
        engrave_front("A2: M3 heatset", w/2, h/2, size=2.5);
        for (i = [0:num_steps-1])
            engrave_back(label_str(nom_m3_heatset, i),
                         i * cell + cell/2, h/2, d, size=2.5);
    }
}

// ========================
// A5: Bolt Counterbore (face-down blind hole + bolt shank)
// ========================
// Counterbore opens at z=0 (bed). At z=depth_counterbore the bore
// narrows to bolt diameter — tests the landing shelf overhang.
module bar_counterbore() {
    cell = cell_size(nom_counterbore);
    w = num_steps * cell;
    d = cell;
    h = depth_counterbore + 4;
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

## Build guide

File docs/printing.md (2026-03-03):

# Printing & Assembly Guide

Complete instructions for printing, calibrating, assembling, and testing the SpeedsterAI enclosure. For a project overview, see the [README](../README.md).

## Print Settings

**Material:** PETG (mandatory for airtightness and stiffness)

**Printer:** Bambu Lab H2D (350×320×325mm build volume). Both halves verified to fit within the build envelope.

| Setting | Value | Rationale |
|---|---|---|
| Layer height | 0.2mm | Good detail/speed balance |
| Perimeters | 5–6 | Fills most of 10mm wall, airtight |
| Infill | 50–80% gyroid | Fills remaining wall, adds damping |
| Top/bottom layers | 8+ | Solid baffle and back face |
| Supports | Minimal | Driver cutouts, counterbores; roundover profile is ≤45° overhang |

**Print orientation:**
- **Front half:** Baffle face DOWN (split face up) — roundover profile designed for ≤45° overhang; best surface finish on visible face
- **Back half:** Flat back face DOWN (split face up) — large flat surface on build plate for best adhesion

## Tolerance Test Print

Before printing the full enclosure, print the tolerance test to calibrate printer-specific fit tolerances. The test produces small bars with feature variants at ±0.3mm in 0.1mm increments, letting you find the exact offset for your printer/material/settings combination.

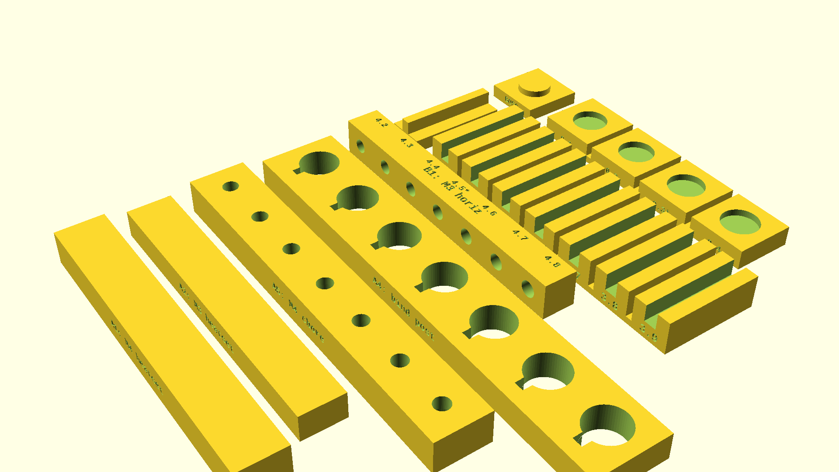
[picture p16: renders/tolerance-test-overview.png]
Tolerance Test Overview


### Exporting the Test STL

```bash
openscad tolerance-test.scad -o models/tolerance-test.stl
```

### Printing the Test

The STL contains four groups that should be separated in your slicer and oriented per their intended print direction:

| Group | Features | Print Orientation |
|---|---|---|
| Face-down plate (A1, A2, A5) | M4 heatset, M3 heatset, M4 counterbore | Holes face DOWN on bed (z=0 on bed) — tests ceiling bridging |
| Through-hole plate (A4) | Binding post keyhole | Either orientation (through-hole) |
| Horizontal plate (B1) | M3 crossover boss insert | Bores enter from side face (Y axis) |
| Mating pieces (C1–C3) | Tongue, groove strip, interlock boss/recess | Flat on bed |

**Use the same print settings as the final enclosure** (PETG, 0.2mm layers, 5–6 perimeters) so the tolerances transfer accurately.

### Testing Each Feature

Each bar has 7 variants labeled with the test diameter (e.g., 5.3, 5.4, **5.6\***, 5.7...). The nominal value is marked with an asterisk (**\***). Group labels are on the front face; diameter values are on the back face.

1. **A1 / A2 — Heat-set inserts:** Press an M4 or M3 heat-set insert into each hole using a soldering iron. Find the tightest hole that still accepts the insert cleanly without excess bulging. Record that diameter.
2. **A5 — Counterbore:** Test-fit an M4 bolt head into each counterbore pocket. The bolt should drop in freely without force. The narrower through-hole above tests the bolt shank clearance.
3. **A4 — Binding post:** Test-fit a binding post terminal. The keyway slot should prevent rotation. Find the variant where the post fits snugly.
4. **B1 — Horizontal insert:** Press an M3 heat-set insert into each horizontal bore. This tests the Z-axis print tolerance (perpendicular to layer lines), which often differs from X/Y tolerance.
5. **C1/C2 — Tongue and groove:** Slide the tongue piece into each groove channel. Find the groove width where the tongue slides smoothly without wobble.
6. **C3 — Interlock:** Press the boss piece into each recess variant. Find the clearance where the boss seats fully with light press-fit resistance.

### Applying Results

Open `speedster-ai.scad` and find the print-tuned dimension variables near the top of the file. Each variable defaults to the design nominal — replace it with the value printed on the test variant that fits best:

```openscad
// Print-tuned dimensions — enter the label value from your best-fit test variant
print_m4_heatset_dia  = 5.6;   // A1: M4 heat-set insert bore diameter
print_m3_heatset_dia  = 4.5;   // A2: M3 heat-set insert bore diameter (X/Y plane)
print_m3_heatset_z    = 4.5;   // B1: M3 heat-set insert bore diameter (horizontal/Z axis)
print_counterbore_dia = 8.0;   // A5: bolt head counterbore diameter
print_bolt_dia        = 4.5;   // A5: M4 bolt through-hole diameter
print_bp_hole_dia     = 11.7;  // A4: binding post panel hole diameter
print_bp_keyway_w     = 2.7;   // A4: binding post keyway slot width
print_groove_w        = 3.6;   // C2: groove channel width
print_seal_depth      = 2.8;   // C4: seal depth below tongue tip for seal cord
print_interlock_clr   = 0.3;   // C3: interlock clearance per side
```

**Example:** You print the tolerance test, try pressing an M4 heat-set insert into each hole on bar A1, and find that the **5.8** variant gives the best fit. Change `print_m4_heatset_dia = 5.8;` — that value is now used for every M4 heat-set bore in the enclosure (woofer mounting, pillar inserts). No offset math required.

After updating, re-export the enclosure STLs:

```bash
./export.sh
```

## Assembly Instructions

1. Print both halves
2. Clean up supports from driver cutouts and counterbores
3. Install M4 heat-set inserts into front half pillars (8× for enclosure bolts)
4. Install M4 heat-set inserts into woofer screw holes (4× from front face)
5. Install M4 heat-set inserts into tweeter recess floor (4× from recess)
6. Install M3 heat-set inserts into crossover boss holes (6× per side wall, from cavity)
7. Mount HP crossover board on left wall, LP board on right wall, with M3 standoff screws
8. Run speaker wire from back to front through split plane
9. Press foam tape or TPU strip into groove on back half split face
10. Add polyfill loosely to cavity
11. Align tongue into groove and interlock bosses into recesses, mate halves
12. Insert 8× M4 bolts from back into front pillar inserts
13. Mount tweeter (flush into recess) with M4 screws
14. Mount woofer (surface mount) with M4 screws
15. Connect drivers to crossover
16. Install binding post plate on rear

## Bill of Materials (per speaker)

### Enclosure Assembly
| Qty | Item | Spec |
|-----|---|---|
| 8 | M4 heat-set inserts | Ø5.7mm × 8mm deep |
| 8 | M4 socket head cap screws | 60mm length |

### Woofer Mounting
| Qty | Item | Spec |
|-----|---|---|
| 4 | M4 heat-set inserts | Ø5.7mm × 6mm deep |
| 4 | M4 socket head cap screws | 10mm length |

### Tweeter Mounting
| Qty | Item | Spec |
|-----|---|---|
| 4 | M4 heat-set inserts | Ø5.7mm × 6mm deep |
| 4 | M4 socket head cap screws | 8mm length |

### Crossover Mounting
| Qty | Item | Spec |
|-----|---|---|
| 6 | M3 heat-set inserts | Ø4.5mm × 6mm deep |
| 6 | M3 standoff screws | 8mm length |

### Seal
| Qty | Item | Spec |
|-----|---|---|
| 1 | Round rubber seal cord | 3mm diameter, enough for perimeter (~700mm) |

### Binding Post Plate
| Qty | Item | Spec |
|-----|---|---|
| 1 | Binding post plate | Dayton Audio SBPP-SI, 100.6mm square |
| 4 | M4 heat-set inserts | Ø5.7mm × 6mm deep |
| 4 | M4 flat head (countersunk) cap screws | 8mm length, 90° head |

### Drivers & Crossover
| Qty | Item |
|-----|---|
| 1 | Tang Band W4-1720 |
| 1 | Fountek NeoCD1.0 |
| 1 | Speedster crossover (see Carmody's BOM) |
| 1 | Polyfill (loose handfuls) |

## Airtightness Test

After assembly, cover the port opening with your palm and gently push the woofer cone inward. It should resist and return slowly. If it springs back quickly, there is a leak at the split joint — check foam tape compression.

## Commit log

2026-02-21 Initial commit: Speedster v2 enclosure
    Complete parametric OpenSCAD model featuring:
    - Curved-back PETG wedge (165x300x185mm, 5.49L)
    - Tang Band W4-1720 + Fountek NeoCD1.0 drivers
    - Front/back split at z=60.7mm with tongue-and-groove seal
    - 8x M4 bolt pattern at split-plane perimeter
    - 16mm pillar pairs with interlock boss/recess system
    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
    [speedster_v2.scad]
2026-02-21 Add project documentation: README, analysis, and AI context
    - README.md: Project overview, BOM, print settings, assembly instructions
    - analysis.md: Design verification covering acoustic fidelity, mechanical
    feasibility, dimensional clearances, and advantages over original
    - claude.md: Full design history and decision rationale for AI agent
    context continuity across sessions
2026-02-23 updated with crossover mounting
    [speedster_v2.scad]
2026-02-23 Crossover boss print support: full 45° brace and D-shaped profile
    - Shift brace start from boss center to boss bottom (ez + boss_r)
    so full cylinder is supported at 45° with no overhang
    - Hull boss cylinder with flat slab to eliminate crescent gaps
    between round boss and flat brace surface
    - Add .gitignore for macOS, OpenSCAD exports, and editor files
    - Update claude.md, README.md, and analysis.md with design rationale
    [speedster_v2.scad]
2026-02-23 Binding plate: heat-set inserts + countersunk M4 screws
    - Convert terminal plate mounting from through-hole self-tappers to
    M4 heat-set inserts (Ø5.6mm × 6mm deep from recess floor)
    - Use M4 flat head countersunk screws to match Dayton Audio SBPP-SI
    plate's countersunk mounting holes
    - Total wall depth used: 3mm recess + 6mm insert = 9mm of 10mm wall
    - Add standard render camera presets and validation images
    [speedster_v2.scad]
2026-02-23 Render pipeline: 7 standard views with corrected camera angles
    - Add render.sh script for CLI-based PNG generation (7 views in parallel)
    - Fix orientation: rotate([90,0,0]) keeps tweeter on top, woofer on bottom
    - 7 views: front, back, side, 3/4 front, 3/4 back, exploded front/back
    - Add render_mode variable (0-4) for assembled/exploded/half/cavity modes
    - Update README.md with render documentation table
    - Update claude.md with Session 10 and render pipeline notes
    - Remove old incorrectly-oriented renders
    [speedster_v2.scad]
2026-02-23 Port entry flare + reinforcement ribs
    - Add 15mm concave entry flare at cavity-side port opening, matching
    the existing exit flare. Reduces turbulence at both port ends.
    - Add bell-shaped tube solid (truncated cone) to provide material
    for the entry flare profile.
    - Add 6 triangular gusset ribs at port tube-to-back-wall junction
    for improved FDM layer adhesion at this critical connection.
    - Update volume estimation to account for entry bell displacement
    (net volume 5.46L, within 0.7% of 5.5L target).
    - Update claude.md (Session 11), README.md, and analysis.md.
    - Regenerate standard render set with new geometry.
    [speedster_v2.scad]
2026-02-23 Fix STL horizontal plane artifacts from hull boundary misalignment
    Rewrote inner_cavity() to use same hull slice z-positions as outer_shape()
    with 0.001mm epsilon offset to prevent both misalignment shelves and
    exactly-coplanar non-manifold edges. Extended port tube 1mm past inner
    back wall and removed intersection(inner_cavity, bosses) to eliminate
    additional coplanar face sources. Non-manifold edges reduced 170 to 159.
    Also adds export.sh for STL generation to models/ directory, and updates
    .gitignore to track models/*.stl.
    [speedster_v2.scad]
2026-02-23 Replace circular roundover with printable Hermite spline profile
    - Circular quarter-arc had 83° overhang at z=0 (unprintable baffle-down)
    - New cubic Hermite spline starts at exactly 45° overhang, monotonically decreasing
    - Added 2mm 45° baffle edge chamfer for smooth front face transition
    - Widened baffle 165→180mm so woofer flange fits on flat face (3.25mm margin)
    - Reduced roundover inset 28→24mm (diffraction effective above ~2281 Hz)
    - Decoupled roundover_depth (39mm) from inset for printability control
    - Inner cavity now tracks roundover profile for uniform 10mm wall thickness
    - Reduced depth 185→174mm to maintain 5.51L target volume
    - Export script rotates back half for flat-b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
    [speedster_v2.scad]
2026-02-24 Adjust print tolerances and fitment dimensions
    - Woofer cutout: 95.5→96.5mm (+1mm clearance)
    - Tweeter recess: 100→100.5mm (+0.5mm clearance)
    - Tweeter body cutout: circular 80mm → cross-shaped 25×67 + 56×47mm
    matching datasheet body profile with 1mm clearance
    - Terminal plate recess: 100.6→100.8mm (+0.2mm clearance)
    - M4 heat-set insert holes: 5.6→5.5mm (all locations)
    - M3 heat-set insert holes: 4.5→4.4mm (all locations)
    - M4 insert pocket depth: 6→8mm (woofer, terminal)
    - M3 insert pocket depth: 5→6mm (tweeter, crossover)
    - M4 bolt through-holes: 4.2→4.3mm (+0.15mm/side FDM clearance)
    [speedster_v2.scad]
2026-02-24 Rename project from Claudsters to SpeedsterAI
    - Rename speedster_v2.scad → speedster-ai.scad
    - Rename STLs: speedster_v2-{front,back}.stl → speedster-ai-{front,back}.stl
    - Update all references in README, claude.md, analysis.md, export.sh, render.sh
    - Remove v2 versioning from all text and filenames (use git for versioning)
    [speedster-ai.scad, speedster_v2.scad]
2026-02-24 Resize enclosure, redesign crossover mounting, update tolerances
    Enclosure resized for crossover clearance behind woofer:
    - Depth 174→185mm, baffle height 300→281mm, back height 240→225mm
    - Volume maintained at 5.498L, split plane auto-adjusts to z=60.7mm
    Crossover PCB mounting redesigned:
    - z_start 62→83mm (clears woofer motor at z=82)
    - y_top tuned to 26mm (inductor clears port tube by 3mm)
    - PCBs rotated 180° in-plane to clear binding post hardware
    - Corner-aware boss positioning via inner_wall_x_at/min_wall_x_in_boss
    - Hole [87,5] removed (corner zone), 3 holes per board
    Tolerances updated from test prints:
    - M4 heat-set insert Ø5.5→5.6mm
    - M3 heat-set insert Ø4.4→4.5mm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
    [speedster-ai.scad]
2026-02-24 Replace terminal plate with direct-mount binding posts
    Replace Dayton SBPP-SI terminal plate (100.8mm square cutout) with two
    Dayton BPP-SNB binding posts mounted directly through the back wall.
    Panel cutout per manufacturer drawing + 0.2mm print tolerance:
    - 2x Ø11.7mm keyhole-shaped through-holes, 30mm center-to-center
    - 2.7mm wide anti-rotation keyway slot per hole (14.2mm from top)
    - Position unchanged at y=-45 on back face
    Benefits:
    - Eliminates 76.5mm square cutout (stiffer back wall)
    - Removes 4x M4 heat-set inserts and screws from BOM
    - Simpler assembly (posts clamp with included nuts)
    [speedster-ai.scad]
2026-02-25 Replace exit flare with printable 45° chamfer, keep 15mm entry bell
    Exit flare (back face):
    - Quarter-circle R15 replaced with 45° linear chamfer in 10mm wall
    - Confined to wall thickness — zero internal geometry change
    - Mouth dia 54.9mm, exactly 45° overhang (printable without supports)
    - Original quarter-circle had 0° overhang at mouth (53 failed layers)
    Entry flare (cavity side):
    - Restored 15mm quarter-circle bell (provides 1.1mm tweeter clearance)
    - Tweeter rear body at 17.5mm from port axis clears bore (18.6mm at z=70)
    - 3.5x area expansion reduces chuffing at port entrance
    Port spec:
    - Bore diameter: 34.925mm (Carmody 1.375" unchanged)
    - Total bore length: 114.3mm (Carmody 4.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
    [speedster-ai.scad]
2026-02-25 Update renders and documentation for port flare changes
    - Regenerated all 7 standard renders
    - Updated claude.md: Session 15 (exit flare printability), updated
    Session 11 (entry flare tweeter clearance), locked parameters table
    - Updated analysis.md: port tuning description, exit flare printability,
    binding post references
2026-02-25 Deepen enclosure to 197mm for tweeter clearance
    Increase enclosure_depth from 185mm to 197mm to eliminate the
    collision between the 50mm square tweeter rear body (including
    terminals) and the port entry bell. The port tube now starts at
    z=72.7mm, 2.7mm past the tweeter's 70mm mounting depth.
    Height reduced to maintain 5.5L target volume:
    - baffle_height: 281 -> 264mm
    - back_height: 225 -> 211mm
    - Net volume: 5.507L (target 5.5L)
    All driver fits, crossover clearance, split plane, and bolt
    pattern remain valid. STLs and renders regenerated.
    [speedster-ai.scad]
2026-02-25 move pcb a bit towards back wall
    [speedster-ai.scad]
2026-02-26 Add component envelope validation system
    - component-envelopes.scad: Simplified 3D envelopes for all components
    (woofer with flange/screws, tweeter with faceplate/screws, full binding
    post profile, per-component crossover with cylinders from KiCad .pos
    data, port tube). 14 analytical assert() clearance checks.
    - validate.py: Geometric collision detection via trimesh/manifold3d.
    Exports 7 STLs, checks 6 containment + 15 pair-wise intersections.
    Handles pass-through components (woofer/tweeter/binding posts).
    - validate.sh: Orchestration (Phase 1: asserts, Phase 2: geometric).
    - render_mode 5 (ghost + envelopes), 6 (front half + drivers),
    7 (back half + internals). validation_export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
    [component-envelopes.scad, speedster-ai.scad]
2026-02-26 Enclosure geometry revision: fix PCB collision, improve clearances
    Resolve three issues found by component envelope validation system:
    1. PCB bottom-back corner collision with curved inner cavity wall
    - back_corner_r reduced 42→17mm (sharper inner corners)
    - enclosure_depth increased 197→205mm (less severe taper at z=182)
    - PCB corners now fully contained within cavity (was -21.5mm gap)
    2. Tweeter-to-port Z-clearance improved
    - Deeper enclosure pushes split_z from 72.7→80.7mm
    - Tweeter-port gap increased 2.7→10.7mm
    3. L3 inductor-port tube collision eliminated
    - port_y_offset raised 45→52mm (zero acoustic impact)
    - L3 inductor now clears port tube by 3mm (wa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
    [component-envelopes.scad, speedster-ai.scad]
2026-02-26 Update README for current design parameters and validation system
    - Specs: volume 5.76L gross (~5.43L effective), depth 205mm, back corners R17,
    roundover 20mm, baffle 180×264mm, back 118×211mm
    - Added component fit render views (transparent shell + color-coded envelopes)
    - Added validation section documenting validate.sh pipeline (20 assertions +
    21 geometric checks)
    - Added crossover mounting to BOM (6× M3 heat-set inserts)
    - Updated assembly instructions for HP/LP boards on separate walls
    - Added file structure section
    - Corrected port flare descriptions (entry bell vs exit chamfer)
2026-02-26 Fix documentation bugs found in pre-print design audit
    - Diffraction frequency: 5462→2737 Hz (was using r=10 instead of r=20)
    Fixed in SCAD, README, analysis.md, claude.md
    - Bolt length: 16→65mm in SCAD print notes, ~60→65mm in README BOM
    - Back half print orientation: 'split face DOWN' → 'back face DOWN'
    - Port clearance echo: hardcoded y=25 → dynamic computation (now +6mm)
    - Port position in analysis.md: y=45→52, z-values updated for depth=205
    - Volume: updated to verified 5.86L gross (STL export), 5.68L net,
    ~5.35L effective. SCAD 3-point Simpson overestimates by 0.08L due to
    roundover zone; documented the discrepancy.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
    [speedster-ai-cavity.stl, speedster-ai.scad]
2026-02-26 Add internal baffle stiffening ribs (spoke-to-pillar pattern)
    Concentric ring (R=60mm) around woofer bore with 7 radial spokes
    extending to each bolt/pillar position. Distributes woofer motor load
    directly to fastener points, breaking the 180x264mm flat baffle into
    smaller stiffened panels with higher natural frequencies.
    - Ring at R=60mm clears woofer rear chamfer, inside screw circle
    - 7 spokes to pillars (top center skipped — crosses tweeter bore)
    - 3mm wide x 15mm tall, clipped to inner cavity
    - All 20 assertions PASS, both halves export NoError
    [speedster-ai.scad]
2026-02-26 Add R=10mm fillet at port exit chamfer junction
    Replace sharp bore-to-chamfer transition with smooth R=10mm concave
    fillet. Built as 12-point arc polygon sweeping 180°→135° (clockwise),
    tangent to both the vertical bore wall and 45° exit chamfer. Reduces
    turbulence at the port exit by eliminating the abrupt diameter change.
    [speedster-ai.scad]
2026-02-26 Add devcontainer with OpenSCAD Manifold backend and Copilot CLI
    - Devcontainer: Ubuntu 24.04 amd64 with OpenSCAD nightly (Manifold
    backend, ~4s STL exports vs minutes with CGAL), xvfb for headless
    rendering, Python validation tools, and Copilot CLI
    - copilot.sh: Launch script with macOS Keychain auth (scoped PAT with
    only Copilot Requests permission), host git identity forwarding,
    and full tool access in the sandboxed container
    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
2026-02-27 Add printer tolerance test print for pre-print calibration
    - tolerance-test.scad: standalone test with 7 feature groups (M4/M3
    heatset, counterbore, binding post, horizontal M3, tongue/groove,
    interlock) generating ±0.3mm variants in 0.1mm steps
    - Print orientation matches enclosure: face-down bars test ceiling
    bridging, horizontal bores test Z-axis tolerance, mating pieces
    are separate for physical fit testing
    - Engraved labels on front (group) and back (diameter) faces
    - Uses include <speedster-ai.scad> to derive center values from
    print_* variables — always stays in sync
    - speedster-ai.scad: replaced tol_* offset variables with absolute
    print_* dimension variables — user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
    [speedster-ai.scad, tolerance-test.scad]
2026-02-28 Restructure docs for release: showcase README + split docs
    - Rewrite README as project showcase with hero renders, three selling
    points (AI collaboration, FDM optimization, acoustic fidelity), and
    links to detailed docs
    - Move detailed content to docs/:
    - docs/printing.md: print settings, tolerance test, assembly, BOM
    - docs/development.md: SCAD usage, pipelines, devcontainer (with
    security boundary documentation)
    - docs/design.md: engineering rationale for every feature
    - Move analysis.md -> docs/analysis.md
    - Rename claude.md -> docs/copilot.md, update all references
    - Add .github/copilot-instructions.md with post-change workflow
    checklist and design constraints for AI agen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
2026-02-28 Add 2mm back edge chamfer to soften rear face edge
    New back_edge_chamfer parameter (2mm, 45° bevel) mirrors the existing
    baffle_edge_chamfer on the front. Implemented via back_inset_at(z) function
    combined with the front roundover inset in cross_section_at(z). Simplified
    cross_section_at by merging two identical code branches into one.
    The chamfer zone (z=203-205) is entirely within the back wall, so internal
    dimensions are unaffected. Printable without supports in the back-face-down
    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
    [speedster-ai.scad]
2026-02-28 Trapezoidal baffle ribs (3:1 taper) + render pipeline speedup
    Baffle ribs: changed cross-section from rectangular to isosceles trapezoid
    (9mm base / 3mm tip / 10mm tall, was 3mm / 3mm / 15mm). Wider base
    increases stiffness at the baffle junction; taper reduces cavity intrusion.
    Ring rib clears woofer bore chamfer by 0.25mm.
    Render pipeline: switched from --preview (software OpenGL via xvfb) to
    --render --backend=Manifold. Total render time ~9s vs ~4min (25x faster).
    [speedster-ai.scad]
2026-03-02 Blender Cycles render pipeline with component-fit views
    - Add Blender to devcontainer, replace OpenSCAD renders with Cycles
    - blender_render.py: translucent shell (--shell-alpha), component STL
    overlays (--component), adaptive sampling, camera tracking fix
    - render.sh: --fast OpenSCAD fallback, component envelope export,
    job throttling (RENDER_JOBS), configurable samples (RENDER_SAMPLES),
    add top view (9→10 views)
    - README: add front/back and side/top render rows, update docs
    - Re-render all PNGs via Blender; remove 7 obsolete OpenSCAD views
2026-03-03 Add print_seal_depth parameter, tune groove/seal defaults, add pillar boss axial clearance
    - Add print_seal_depth (2.2mm) to print-tunable parameters — was hardcoded at 2.8mm,
    now calibratable via tolerance test C4
    - Update print_groove_w nominal from 3.4mm to 3.3mm
    - Add 0.4mm axial clearance on pillar interlock bosses (boss 1.6mm, recess 2.0mm)
    to ensure split faces seat flush despite print variation
    - Update docs/printing.md with new parameter
    - Regenerate back half STL, tolerance test STL, and all renders
    [speedster-ai.scad]
